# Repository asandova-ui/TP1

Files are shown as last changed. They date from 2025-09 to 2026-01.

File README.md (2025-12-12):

***ESTRUCTURA DE DESCOMPOSICIÓN DEL PROYECTO***
**Especificación del proyecto**
Definición de objetivos  
Estudio sistema  

**Diseño electrónico y captura esquemática PCB0** 
Búsqueda de componentes  
Posicionado componentes  
Creación de nuevos componentes  
Documentación esquemático. Control de cambios  
Análisis consumo eléctrico  
Análisis disipación de potencia  
Rutado de conexiones  
Generación de listado de materiales (BOM) 

**Diseño electrónico y captura esquemática PCB1** 
Búsqueda de componentes  
Posicionado componentes  
Creación de nuevos componentes  
Documentación esquemático. Control de cambios  
Análisis consumo eléctrico  
Análisis disipación de potencia  
Rutado de conexiones  
Generación de listado de materiales (BOM)  

**Diseño electrónico y captura esquemática PCB2** 
Búsqueda de componentes  
Posicionado componentes  
Creación de nuevos componentes  
Documentación esquemático. Control de cambios  
Análisis consumo eléctrico  
Análisis disipación de potencia  
Rutado de conexiones  
Generación de listado de materiales (BOM)  

**Diseño electrónico y captura esquemática PCB3** 
Búsqueda de componentes  
Posicionado componentes  
Creación de nuevos componentes  
Documentación esquemático. Control de cambios  
Análisis consumo eléctrico  
Análisis disipación de potencia  
Rutado de conexiones  
Generación de listado de materiales (BOM)  

**Diseño de la placa de circuito impreso PCB0** 
Creación de huellas de nuevos componentes  
Posicionado de componentes  
Definición de borde y zonas de conectores 
Rutado de conexiones  
Planos de disipación térmica  
Planos de masa y otros  
Documentación: serigrafía. Control de cambios 
Documentación: acotaciones geométricas  
Generación de ficheros para el fabricante (gerber)  

**Diseño de la placa de circuito impreso PCB1** 
Creación de huellas de nuevos componentes  
Posicionado de componentes  
Definición de borde y zonas de conectores 
Rutado de conexiones  
Planos de disipación térmica  
Planos de masa y otros  
Documentación: serigrafía. Control de cambios 
Documentación: acotaciones geométricas  
Generación de ficheros para el fabricante (gerber)  

**Diseño de la placa de circuito impreso PCB2** 
Creación de huellas de nuevos componentes  
Posicionado de componentes  
Definición de borde y zonas de conectores 
Rutado de conexiones  
Planos de disipación térmica  
Planos de masa y otros  
Documentación: serigrafía. Control de cambios 
Documentación: acotaciones geométricas  
Generación de ficheros para el fabricante (gerber)  

**Diseño de la placa de circuito impreso PCB3** 
Creación de huellas de nuevos componentes  
Posicionado de componentes  
Definición de borde y zonas de conectores 
Rutado de conexiones  
Planos de disipación térmica  
Planos de masa y otros  
Documentación: serigrafía. Control de cambios 
Documentación: acotaciones geométricas  
Generación de ficheros para el fabricante (gerber)  

**Fabricación de la placa de circuito impreso** 
Envío al fabricante  
Recepción y revisión  
Montaje de componentes  

**Realización Hardware FPGA**
Core: LarVA 
Periféricos: UART0/1/2, SPI0/1, Temporizador, GPOut, GPIn 
Simulación 

**Realización Firmware. Simulación y depuración** 
Control de elementos hardware: drivers  
Verificación  
Programa principal. Especificaciones  
Documentación firmware. Control de cambios  

**Verificación hardware** 
Verificación inicial  
Verificación firmware 
Resolución de problemas  
Análisis de prestaciones  
Montaje final. Piezas mecánicas  
Pruebas de campo 

**Documentación** 
Realización informe

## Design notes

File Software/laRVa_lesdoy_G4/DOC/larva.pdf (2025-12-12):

## LaRVa

## Last “Another RISC-v” from VAlladolid

J. Arias

## 1 Introduction

LaRVa is a minimal RV32E/RV32I core designed with three goals in mind:

1. It has to be simple, easy to understand, and to fit into small FPGAs.
2. It has to run fast.
3. It has to support vectored interrupts.

Goal #1 was dictated by the FPGAs we are using in lots of designs: the ICE40HX family from Lattice, and also by common sense.
Goal #2 implies a pipelined execution, something I explored with success in the design of the GUS16 processor, and that most simple RV cores, like “PicoRV” from Claire Wolf, or “FemtoRV” from Bruno Levy & Matthias Koch, lack. laRVa is going to execute one instruction each clock cycle, unless these instructions are loads, stores, or jumps.
Goal #3 demands some way to save the value of the PC when an interrupt is serviced. I resorted to use two different PC registers, one for normal mode and other for interrupts, so there is no need to save anything.
Why to design another CPU core? Well, the GUS16 was a successful design, but with a very big problem: It has no GCC toolchain! Its only tool is a lousy 2-pass assembler and that’s all folks. Apart from that it is a 16-bit design with many limitations. On the contrary, the RISC-V have a powerful toolchain maintained by GNU and it is a 32-bit design.
Of course, this design is going to present some challenges apart from the fact that it uses double the number of bits than the GUS16, like:
- A big register bank that can’t be mapped to internal RAM blocks (BRAMS). The problem with BRAMS is their synchronous read, or the fact that the data you are reading isn’t available until next clock edge, a time I don’t want to waste. 32 registers of 32 bits each will require no less than 1024 flip-flops or logic cells, so a 16-register approach (RV32E) could be a good idea to start with.
- A lot of sign extensions are needed for literals and also for the bytes and half-words read from memory. And, in some cases zero extensions.
- The usual ALU has to be complemented with a barrel shifter in order to support single cycle multi-bit shifts.
- The “Set Less Than” instructions also have to be supported in the ALU.
- Conditional branches do use the ALU for the checking of conditions (there are no comparisons, nor condition flags here), but they also require the addition of an literal offset to PC, thus, a second adder has to be included for the PC update during jumps.

- Talking about PC offsets. In the RISC-V ISA all offsets are related to the address of the current instruction, but in a pipelined processor the PC is going to point ahead of the instruction being executed. This fact has to be taken into account in the processor design (not in the assembler like in the GUS16 case, or ARMs, or many others)
- While the RISC-V ISA is very clear and concise about its base integer instructions, when it comes to privileged mode it becomes just the contrary. I’m not going to waste a single logic cell for the implementation of a “Vendor ID” register, profiling register, or any crap like that. I just want a minimally decent implementation of hardware interrupts, so, the only register I’m planning to implement is the “MEPC” (Machine Exception PC) along with the “MRET” instruction for copying it back to PC or something equivalent like the use of two PC registers.

## 2 LaRVa design

This processor follows a pipelined execution where two instructions are processed in parallel: One gets its op-code read from memory and the other gets executed. An Instruction register holds the op-code while a new one is being read, and all instructions must complete their execution in a single cycle. This last requirement leaves out the multiplication and division instructions and forces the use of a barrel shifter in the ALU, along with ruling out the use of BRAM blocks with synchronous outputs for the synthesis or the register file.
Also, not all instructions can be executed in this way: Load and Store operations have to address the memory during their execution cycle, and therefore, no op-code fetch can be carried out simultaneously. In this case an invalid op-code is stored in the instruction register and it has to be signaled and discarded. This results in the use of two effective clock cycles for the execution of Load or Store instructions. Something similar happens during jumps, where the op-code read into the instruction register is the one at the memory position following the jump instruction, and that instruction shouldn’t be executed. In the case of jumps two effective cycles are also employed, and conditional jumps will take two cycles if their condition is meet or just one cycle otherwise. Apart from these details, the design of the LaRVa core is quite conventional with three data buses: two inputs and one output to the ALU. A good deal of Verilog code was taken from the “FemtoRV” sources, specially that related to the ALU design or the Load/Store management. Some of this code remains almost untouched, like the mentioned Load/Store logic, while other was heavily modified, like the ALU. And, of course, some other code is completely new, like the register file, the the program counter stack (LaRVa has two PCs), and the interrupt logic, that was almost literally copied from the GUS16 design.
With respect to the FemtoRV design I want to remark the following changes:
- The ALU is now used for the computation of memory addresses during the execution of Load and Store instructions. The address bus is switched from the PC to the output of the ALU adder during these instructions.
- The ALU is also used for the computation of the jumping address for the JALR instruction, and the results of the AUIPC and LUI instructions.
- There are no separate adder and subtractor circuits in the ALU. These two blocks were merged.

### 2.1 General diagram

A general view of the design is presented in the following diagram:

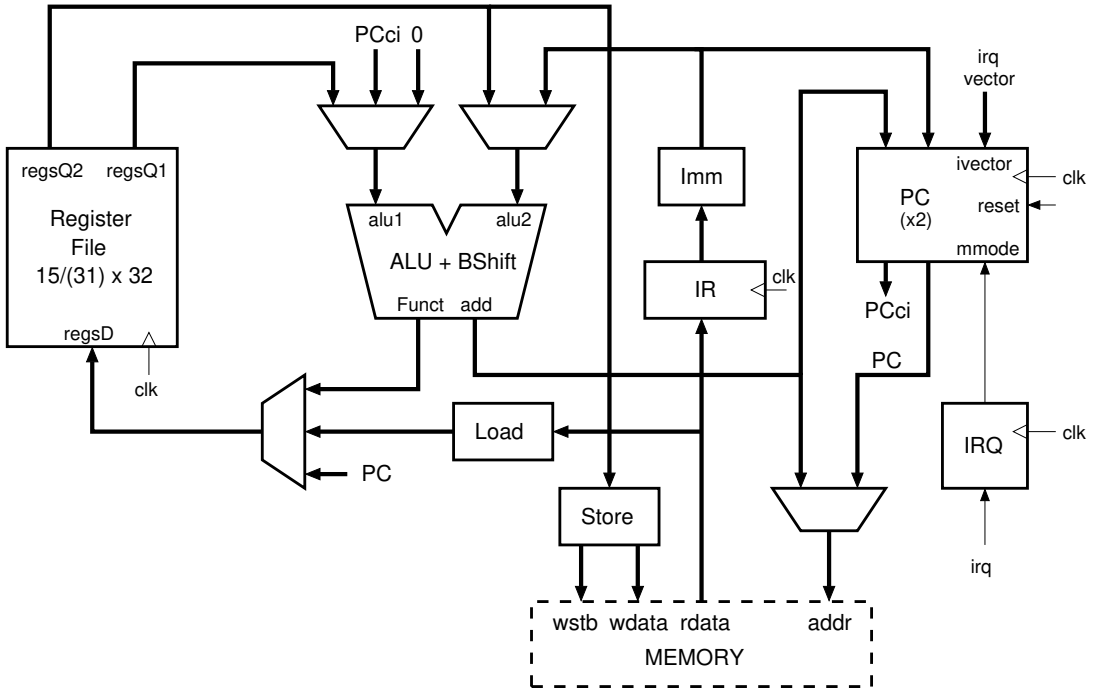
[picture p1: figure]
Register File 15/(31) x 32; regsD; regsQ2; regsQ1; add; Imm; Load; mmode; reset; IRQ; irq; clk; wstb wdata rdata; addr; MEMORY; Store; ALU + BShift; irq vector; ivector; alu1; alu2; Funct; PCci 0; PCci

Here, most blocks are combinational and they are controlled by the bits stored in the IR register, that holds the op-code of the instruction being executed. IR also holds the bits of the immediate values that are further processed in the Imm block, mainly for bit descrambling and sign extension.
The ALU includes mainly an adder and a barrel shifter. In its output the desired operation (ADD, SUB, AND, OR, XOR, Shifts,...) can be selected, but the output of the adder is also always present. This second output is used for the generation of the memory address during Load and Store instructions, and also by the JALR instruction (in fact, the main output of the ALU could also be used, but it has a little longer delay). The first ALU input is usually the contents of the register “rs1”, but it can be also the delayed PC for the AUIPC instruction or even zero for the LUI instruction. The second ALU input is selected between the register “rs2” or an immediate constant
The value written back to the register file (register “rd”) is the output of the ALU for most cases, a value derived from the data coming from memory for Load instructions, or the current value of the program counter (address of next instruction) for the JAL and JALR instructions. No value is written back in the case of Store, Branch, System instructions other than CSRRW, or in the case of invalid values in IR (pipeline stalls).
The program counter block will be described in detail next. Here I want to remark that it is actually a two-level stack that resembles the case of 8-bit PIC microcontrollers. One of its registers is used during normal program execution, while the other is switched in when an interrupt happens. The normal PC remains unchanged during the execution of interrupt routines and it is switched back when a return from interrupt (MRET) is executed. Also, while in normal mode, the interrupt PC gets preloaded with a vector that could be made different for each possible interrupt source.
The only remaining block is the one related to interrupt management, that will be detailed later.

### 2.2 Program counter

A more detailed diagram of the Program Counter logic is shown next:

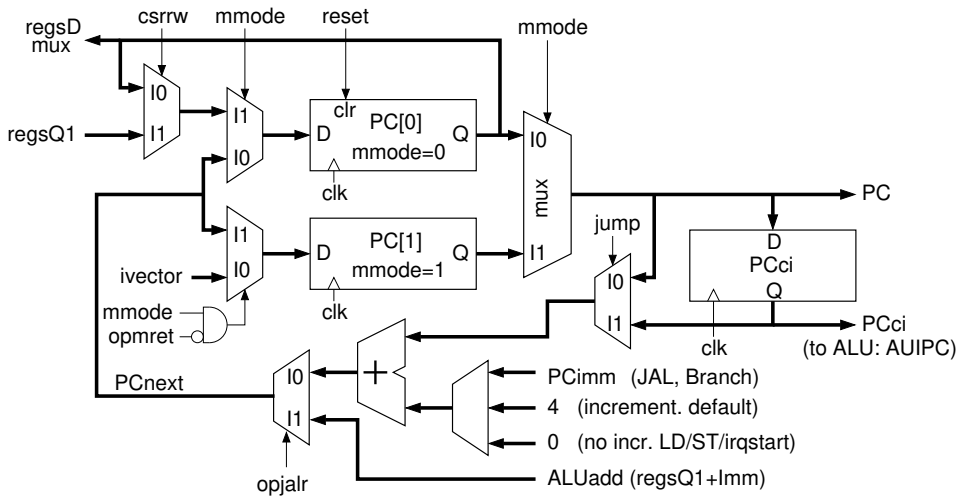
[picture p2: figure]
I1mux; mmode=0; PC[1] mmode=1; mmode; opmret; opjalr; (no incr. LD/ST/irqstart); (increment. default); PCnext; ivector; csrrw; reset; regsQ1; mux; regsD; ALUadd (regsQ1+Imm); PCimm (JAL, Branch); clr; clk; PCci; PCci Q; (to ALU: AUIPC); jump

The “mmode” signal selects which register to present at the output, and also the values written back to each register. In normal mode (mmode=0) the register PC[0] is selected as output and it is updated every clock cycle, while the register PC[1] is written with the value “ivector”, that is the address of the next interrupt service routine. In interrupt (AKA machine) mode PC[0] remains with it last value stored and PC[1] is presented at the output and updated.
There is also another register, “PCci” (PC of current instruction), where the PC value is copied, so, it has the same value as the PC but with a one cycle delay. This register holds the address of the instruction currently being executed and its contents are used for the computation of branch and JAL address, and for the AUIPC instruction. (I think a register is cheaper and faster than an adder for the subtraction of 4).
The update logic is built around an adder that allows the PC incrementing (as op-codes are 32-bit long the PC increments in steps of 4), the addition of offsets for the execution of conditional branches and the JAL instruction, or to leave the PC as it is (increment of 0), that is also required during the execution of Load and Store instructions, or when the mode changes to interrupt. The JALR instruction is an special case because the jumping address is computed in the ALU (the base register is one of the register file, not the PC), and the ALU output has to be switched in during the execution of JALR.
The actual update logic built in the Verilog source is functionally equivalent to that shown in the figure but a little different:

// Next PC logic

wire [31:0]PCadd1= PC+(irqstart | opload | opstore ? 0 : 4);

wire [31:0]PCadd2= PCci+PCimm;

wire [31:0]PCnext= opjalr ? aluAdder : (jump? PCadd2 : PCadd1);

Here two separate adders are used and their results switched depending on “jump”. “jump” is a decoded signal for a taken jump and it can have a quite long delay due to the checking of condition codes in the ALU. This delay would be added to that of the PC update adder if the logic of the figure is implemented as shown. The actual implementation is faster because all adders are going to have a valid result more or less as the same time when “jump” becomes valid, but it requires more logic.
The AND gate that controls the writing of PC[1] is intended for the chaining of interrupts, and it forces the writing of “ivector”, even in interrupt mode, when the MRET instruction is executed.
I want to notice that during interrupt mode the register PC[0] is acting as an effective MEPC (Machine Exception PC) and it would be interesting to be able to read and to modify it. That would provide support for task switching. In order to have a minimally compliant implementation of the related privileged ISA the CSRRW instruction was also added to the core instruction set, yet restricted to its use with the control/status register #0x341 (MEPC). This instruction allows the atomic read plus write of the MEPC register, that is in fact PC[0].
So, now we have two privileged instructions that can be used only in machine mode. If they are executed in the normal user mode they will fail for sure. These instructions are:
1. MRET. When executed in machine mode returns to user mode and restores the original PC (if there are no interrupts still pending) returning to the interrupted program. If executed in user mode it does nothing.
2. CSRRW rd,0x341,rs1. When executed in machine mode copies the value of PC[0] (MEPC) to “rd” and the value of “rs1” to PC[0]. No other offsets in the CSR space are allowed. If executed in user mode PC[0] isn’t written, but in “rd” we get the current value of PC.

On the other hand, the instructions ECALL and EBREAK (software interrupts) will do nothing if executed in machine mode.

### 2.3 Interrupts

The servicing of an interrupt implies the changing of the “mmode” signal to 1, but this has to be done in a proper sequence in order to avoid disturbing the instruction being executed. That instruction has to complete its execution cycle with the normal PC still selected. In order to achieve this an “irqstart” signal is set during just one clock cycle before “mmode” is set , and this signal will cause a pipeline stall, so no instruction will be executed with a wrong PC register selected.
The details of such sequencing are shown in the next chronograph:

mmode

irqstart

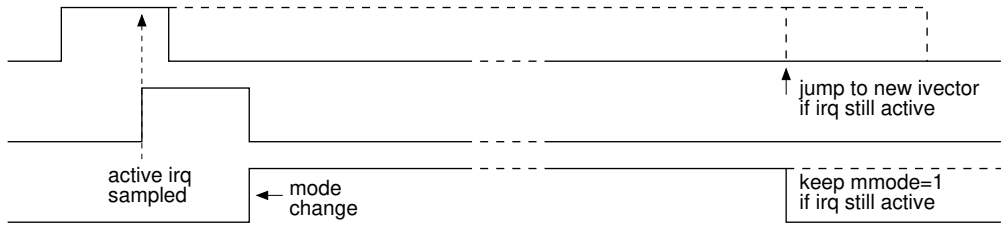
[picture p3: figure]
jump to new ivector; change; mode; keep mmode=1; sampled; active irq; if irq still active

irq

clk

opvalid | invalid fetch
discard | discard

MRET

Exec

Fetch
MRET
op−code | op−code

invalid
fetch
no PC
incr.

Also, at the end of the interrupt routine an MRET instruction is executed. That instruction usually returns “mmode” to 0 and causes a pipeline stall just like any other jump, but, if the “irq” line is still active “mmode” remains at 1 and interrupts are thus chained.
The circuit diagram for the interrupt sequencing is shown next. It is almost the same as in the GUS16 core:

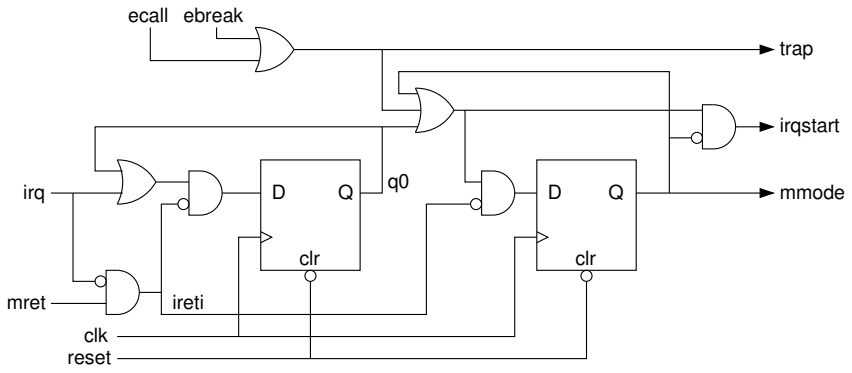
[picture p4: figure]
clr; reset; irq; clk; mret; trap; mmode; ecall ebreak; ireti; irqstart

There was also a need for some sort of “software interrupt”, so, the ECALL and EBREAK opcodes were also decoded and they act in a similar way to the “irqstart” signal, entering the interrupt mode. But I didn’t want to provide a particular interrupt vector for these opcodes, so, I resorted to provide a “trap” output for the core that can be routed to an external vectored interrupt controller just like any other interrupt from a peripheral.

### 2.4 Memory interface & Wait States

The LaRVa core has a simple memory interface, including:

- “[31:2]addr”, the memory address. It lacks the two lower bits because these address are for bytes and the data bus is 32-bit wide.
- “[31:0]rdata”, the data read from the memory/IO system. Its has 32 bits, but for byte and half-word loads some of these bits are ignored.
- “[31:0]wdata”, the data to write to the memory/IO system. For byte and half-word stores some of these bits are invalid and shouldn’t be written (see write strobes next).
- “[3:0]wstrb”, the four write strobes:
wstrb | bits to write | Instruction
0001 | wdata[7:0] | SB
0010 | wdata[15:8]
0100 | wdata[23:16]
1000 | wdata[31:24]
0011 | wdata[15:0] | SH
1100 | wdata[31:16]
1111 | wdata[31:0] | SW

I want to remark that “addr” changes after each rising edge of “clk” and “rdata” must be valid before the next rising edge. Or in other words: The memory is supposed to be an asynchronous one. If this core is to be interfaced to a synchronous RAM, like that found inside FPGAs, it’s a good idea to use an inverted clock for the memory. That would change the RAM output on the falling edges, half a cycle before its sampling by the core.
With respect to other cores, like PicoRV or FemtoRV, there are two control lines missing:
- “mem_valid” output. The LaRVa core is reading or writing the memory all the clock cycles, so, a “mem_valid” signal would be always active.
- “mem_ready” input. There is no control input to force the insertion of wait states in the core. This may difficult the interfacing of slow memory devices, like the “SPI_flash_as_ROM” ones, or other memorymaster devices like video controllers or DMA. But not too much. The trick here is to force the core clock as high when wait cycles have to be inserted and it requires a simple OR gate (a trick taught by Mr Clive Sinclair in its ZX Spectrum).

### 2.5 Interrupt interface

The core has two inputs and one output related to interrupts. These are:

- “irq”. This input requests a change to interrupt (machine) mode and a jump to an interrupt service routine when high. The ISR starts its execution two clock cycles after “irq” is sampled high.

- “[31:2]ivector”. A 30-bit interrupt vector with the address of the interrupt routine to jump. Code addresses have to be multiple of 4, so, the bits 1 and 0 are missing.
- “trap”. An output that signals the execution of a software interrupt (or environment call, system call, kernel entry, or whatever you like to call it). The only instructions that make “trap” to go high are ECALL and EBREAK. This signal can be used to generate a convenient vector address for these software interrupts outside the core. In the external interrupt controller “trap” has to have the maximum priority or ECALL/EBREAK interrupts could be missed if a higher priority interrupt happens at the same time (“trap” is active for only one cycle). In the LaRVa core there is no difference between ECALL and EBREAK, but a trap handler could read the value of MEPC, inspect the opcode of the interrupting instruction, and take a different course of action depending on it.

## 3 Performance

The LaRVa core is supposed to be fast and this ought to be tested. As a benchmark I wrote an small program in C language that does fixed-point FFTs and ran it in both the LaRVa and PicoRV cores. I would like to include the FemtoRV core too, but the naked truth is that I never got working the same core I used for much of the LaRVa logic, and I don’t want to expend more time on it.
Both cores were running at 18MHz, but while LaRVa was just an RV32E core without support for multiplications, the PicoRV core was an RV32IMC that included multiplications in its instruction set. And multiplications are the very basic processing block for FFTs. But anyway, the times taken for the calculation of 400 FFTs with 128, 16-bit, samples each were recorded.
Along with the FFT I also included another different test: An Eratosthenes sieve for finding the prime numbers below 2048. This last test is less dependent on multiplications and more on multi-bit shifts. The results for both test are:
Core | ISA | Fixed-point FFT | Eratosthenes sieve
measured Time | speed factor | measured Time | speed factor
PicoRV | RV32E | 18.31 s | 95% | 36.71 ms | 94%
| RV32I | 17.36 s | 100% | 34.52 ms | 100%
| RV32IC | 17.53 s | 99% | 35.65 ms | 97%
| RV32IM | 3.69 s | 470% | 20.45 ms | 169%
LaRVa | RV32E | 6.63 s | 262% | 13.60 ms | 254%

Here we can see that the ISA chosen for the PicoRV has little impact on the time unless there are multiplications involved. Leaving multiplications apart we see that the LaRVa core runs 2.76 times faster when executing exactly the same code than the PicoRV. This is almost what was expected because LaRVa is 3 times faster for normal instructions and 2.5 times faster for loads, stores, and jumps, according to the times stated by Claire. If we take the advantage of a larger register file into account the picture doesn’t change too much, the time is reduced by only a 5%. Also, the use of a compressed instruction set leaves the execution time almost unchanged. Only when we add hardware multiplications to the ISA we can see an spectacular improvement in execution time for the FFT test, but we must recall this test is heavily biased towards multiplication efficiency. For the Eratosthenes sieve the execution time is also reduced in the RV32IM case, but not as much. In this case the improvement is due to the DIV and REM instructions used during binary to decimal conversion for the printing of the prime numbers (The I/O time of the output peripheral isn’t included in the table).
An still faster multiplication for the PicoRV was untested because I ran out of FPGA space when synthesizing it.

To be honest, the LaRVa was running at its maximum clock frequency while the PicoRV still could be made to run a 34% faster because its maximum clock frequency was 24.26MHz. But still, if we take into account the maximum clock frequencies reported by “nextpnr” and we scale the times accordingly, the LaRVa core runs almost twice as fast than the PicoRV core as long as the code don’t rely heavily on multiplications.

## 4 Multitasking

Or multitrheading, or... Names change with time but things are still the same. In order to switch to a different task we have to:

- Switch to privileged mode. This can be done via executing ECALL or by a peripheral interrupt.
- Save all the register values in a memory area. The stack of the task would be a convenient place (each task is going to have its private stack area)
- Save also the value of the MEPC register.
- Save the current value of the stack pointer in a task table.
- Now, select a different task to switch and get the value of its stack pointer.
- Read the MEPC value from the new stack and write it to MEPC.
- Read the values of all the registers from the stack.
- Go back to user mode by executing MRET.

An example of a simple Round-Robin task switcher is listed next:

void __attribute__((naked)) task_switch() {
asm volatile(
" | addi | sp,sp,-60 | \n"
" | sw | x1,0(sp) | \n"
" | sw | x3,4(sp) | \n"
" | sw | x4,8(sp) | \n"
" | sw | x5,12(sp) | \n"
" | sw | x6,16(sp) | \n"
" | sw | x7,20(sp) | \n"
" | sw | x8,24(sp) | \n"
" | sw | x9,28(sp) | \n"
" | sw | x10,32(sp) | \n"
" | sw | x11,36(sp) | \n"
" | sw | x12,40(sp) | \n"
" | sw | x13,44(sp) | \n"
" | sw | x14,48(sp) | \n"
" | sw | x15,52(sp) | \n"
" | csrrw | x1,0x341,zero | \n" // Interrupted PC
" | sw | x1,56(sp) | \n"
" | mv | a0,sp | \n"
" | call | getnextsp | \n"
" | mv | sp,a0 | \n"
" | lw | x1,56(sp) | \n"
" | csrrw | zero,0x341,x1 | \n" // Interrupted PC
" | lw | x1,0(sp) | \n"
" | lw | x3,4(sp) | \n"
" | lw | x4,8(sp) | \n"
" | lw | x5,12(sp) | \n"
" | lw | x6,16(sp) | \n"
" | lw | x7,20(sp) | \n"
" | lw | x8,24(sp) | \n"
" | lw | x9,28(sp) | \n"
" | lw | x10,32(sp) | \n"
" | lw | x11,36(sp) | \n"
" | lw | x12,40(sp) | \n"
" | lw | x13,44(sp) | \n"
" | lw | x14,48(sp) | \n"
" | lw | x15,52(sp) | \n"
" | addi | sp,sp,60 | \n"
" | mret | | \n"
);
}

// task table
#define MAXTSK 4

struct {
uint32_t tskix; | // Current task index
uint32_t tsksp[MAXTSK]; // list of SPs
} tsktab;

// Scheduler: round-robin: Saves SP and gets a new one fron the task list uint32_t getnextsp(uint32_t sp)
{
uint32_t i;
i=tsktab.tskix;
tsktab.tsksp[i]=sp;
i++;
if (!tsktab.tsksp[i]) i=0; // Task list ends with SP=0 sp=tsktab.tsksp[i];
tsktab.tskix=i;
return sp;
}

#define STKSZ0 (1<<10) // Stack size for task 0

void init_task()
{
uint32_t *sp;
sp=(uint32_t *)(0x20000000+(128<<10)-STKSZ0);
sp=&sp[-15];
sp[14]=(uint32_t) tetris_task1; // PC of task #1 at its stack
tsktab.tskix=0; | // Current task number
// task #0 is the current code and needs no initialization
tsktab.tsksp[1]=(uint32_t)sp; | // SP of task #1
tsktab.tsksp[2]=0; | // End of task list
IRQVECT0=(uint32_t)task_switch; // trap vector
}

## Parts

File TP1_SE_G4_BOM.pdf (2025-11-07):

## Bill Of Materials for Taller Proyectos 1. Datalogger

Design Title | Taller Proyectos 1. Datalogger
Author | G4: Andrés, Iván, Lucía, Víctor R, Alonso
Document Number | 1
Revision | 1
Board | PCB0-Power-USB
Design Created | miércoles, 21 de septiembre de 2022
Design Last Modified viernes, 7 de noviembre de 2025

### Total Parts In Design 61

### Notes

Falta el IVA (21%)
9 Capacitors
Quantity References | Value | Stock Code | PCB Package | Unit
| | | | | Cost
2 | C20,C26 | 100nF | . | 0805 | €0,10
4 | C21-C24 | 22uF | . | 0805 | €0,09
1 | C25 | 1uF | . | 0805 | €0,12
2 | C27-C28 | 33pF | . | 0805 | €0,10
Sub-totals: | | | | | €0,88
16 Resistors
Quantity References | Value | Stock Code | PCB Package | Unit
| | | | | Cost
1 | R15 | 220R | . | 0805 | €0,09
3 | R16,R27-R28 | 2k2 | . | 0805 | €0,09
1 | R17 | 71.5k | . | 0805 | €0,09
4 | R18,R23-R24,R30 | 10k | . | 0805 | €0,09
2 | R19-R20 | 0R1 | . | 0805 | €0,09
2 | R21-R22 | 470R | . | 0805 | €0,09
2 | R25-R26 | 680R | . | 0805 | €0,09
1 | R29 | 4k7 | . | 0805 | €0,09
Sub-totals: | | | | | €1,44
4 Integrated Circuits
Quantity References | Value | Stock Code | PCB Package | Unit
| | | | | Cost
1 | U4 | MCP73831/2 | Farnell 1332157 | SOT23-5 | €0,64
1 | U5 | MCP1725ADJ | Farnell 1834878 | SO8 | €0,66
1 | U6 | CY7C65213-28PVXI Farnell 2772892 | SOP65P780X200-28 €1,73
1 | U7 | LPC1112FD20/102 | Mouser 771- LPC1112FD20/1025 | SO20W | €2,47
Sub-totals: | | | | | €5,50
3 Diodes
Quantity References | Value | Stock Code | PCB Package | Unit
| | | | | Cost
2 | D2-D3 | KA-3022SRC-4.5SF- TR | Farnell 4665975 | SOD123_K | €0,45
1 | D4 | KA-3022SGC-4.5SF Farnell 1142615 | SOD123_K | €1,68
Sub-totals: | | | | | €2,58
29 Miscellaneous
Quantity References | Value | Stock Code | PCB Package | Unit
| | | | | Cost

21 | /BOOT,/HOLD,/ICE_RESET,/RESET,
/SS,/WP,3V3,3V7,3V3M,3V7M,5V, GND,ICE_CLK,ICE_DONE,MISO, MOSI,RXD,SCK,TXD,USB_D+,USB_D-
PIN | PIN | €1,86
1 | BAT | 530480310 | Digikey WM1743- ND | 530480310 | €2,60
1 | BAT1 | LIPO BAT | ampul AM9299 | NULL | €3,20
1 | J4 | USB Mini B Molex 67503-1230 | Farnell 2847248 | MOLEXUSB MINI B 67503-1230 | €11,40
1 | J11 | 2214S-40SG-85 | Farnell 2847248 | CONN-DIL40- ROUND | €0,65
1 | J12 | 2214S-40GS-85 | Farnell 2313554 | CONN-DIL40- ROUND | €0,65
1 | L1 | MMZ1608B121C | Farnell 2800823 | RESC1608X84 | €0,09
1 | SW1 | OS102011MA1QS1 | Farnell 2435103 | OS102011MA1QS1 €4,55
1 | X1 | QT49-12.000MEEJ- B | Farnell 4200031 | QT49-12.000MEEJ- B | €0,35
Sub-totals: | | | | | €62,55
Totals: | | | | | €72,95

viernes, 7 de noviembre de 2025 11:16:01

## Bill Of Materials for Taller Proyectos 1. Datalogger

Design Title | Taller Proyectos 1. Datalogger
Author | G4: Andrés, Iván, Lucía, Víctor R, Alonso
Document Number | 1
Revision | 1
Board | PCB1-FPGA
Design Created | miércoles, 21 de septiembre de 2022
Design Last Modified viernes, 7 de noviembre de 2025

### Total Parts In Design 94

### Notes

Falta el IVA (21%)
20 Capacitors
Quantity References | Value | Stock
| | | Code | PCB Package | Unit Cost
16 | C1-C8,C11-C17,C20 | 100nF | . | 0805 | €0,10
2 | C9-C10 | 10uF | . | 0805 | €0,10
2 | C18-C19 | 22uF | . | 0805 | €0,09
Sub-totals: | | | | | €1,98
51 Resistors
Quantity References | Value | Stock
| | | Code | PCB Package | Unit Cost
6 | R1,R9-R10,R14,R49-R50 | 10k | . | 0805 | €0,09
2 | R2,R47 | 33k | . | 0805 | €0,09
2 | R3-R4 | 100R | . | 0805 | €0,09
3 | R5-R7 | 2k2 | . | 0805 | €0,09
1 | R8 | 0R1 | . | 0805 | €0,09
1 | R11 | 12k | . | 0805 | €0,09
1 | R12 | 4k7 | . | 0805 | €0,09
1 | R13 | 1k5 | . | 0805 | €0,09
4 | R15-R18 | 680R | . | 0805 | €0,09
9 | R19,R21,R23,R28,R30,R32,R37,R39, R41 | 180R | . | 0805 | €0,09
15 | R20,R22,R24-R25,R27,R29,R31,R33- R34,R36,R38,R40,R42-R43,R18B | 330R | . | 0805 | €0,09
3 | R26,R35,R44 | 130R | . | 0805 | €0,09
2 | R45-R46 | 68R | . | 0805 | €0,09
1 | R48 | 0R | . | 0805 | €0,09
Sub-totals: | | | | | €4,59
4 Integrated Circuits
Quantity References | Value | Stock
| | | Code | PCB Package | Unit Cost
1 | U1 | ICE40HX4K-TQ144 | Farnell
| | | 3768754

QFP50P2200X2200X160-144N €9,20

1 | U2 | IS25LP032D-JNLE | Farnell
| | | 1852016 | SO8W | €2,63
1 | U3 | MCP1725ADJ | Farnell | SO8 | €1,05
1 | U5 | MCSJK-3N-16-3.3-50- B | Farnell | MCSJK3N16003350B
Sub-totals: | | | | | €12,88

5 Diodes
Quantity References | Value | Stock
Code
| | | PCB Package | Unit Cost
1 | D1 | 1N4448HWS | Farnell
3127174
| | | SOD-323 | €0,12
2 | D2-D3 | KA-3022SRC-4.5SF- TR
Fernell
4665975
| | | SOD-323 | €0,34
1 | D4 | KA-3022SRC-4.5SF- TR
Fernell
4665975
| | | SOD-323 | €0,45
1 | D5 | KA-3022SRC-4.5SF- TR
Fernell
4665975
| | | SOD-323 | €0,38
Sub-totals: | | | | €1,63
14 Miscellaneous
Quantity References | Value | Stock
Code
| | | PCB Package | Unit Cost
7 | 1V2,1V2M,BLUE,GREEN,HSY,RED, VSYNC | PIN | PIN
2 | 3V3,GND | PIN | PIN | €0,00
2 | J1-J2 | M20-6102045 | Farnell
1569230
| | | CONN-DIL40-ROUND | €5,32
1 | J3 | L77HDE15SD1CH4F Farnell
2401182
| | | L77HDE15SD1CH4F | €1,88
2 | MB0-MB1 | SPC20485 | Farnell
1258956
| | | CONN-SIL2 | €0,46
Sub-totals: | | | | €13,44
Totals: | | | | €34,52

viernes, 7 de noviembre de 2025 11:16:21

## Bill Of Materials for Taller Proyectos 1. Datalogger

Design Title | Taller Proyectos 1. Datalogger
Author | | G4: Andrés, Iván, Lucía, Víctor R, Alonso
Document Number | 1
Revision | 1
Board | PCB2-Sensors
Design Created | miércoles, 21 de septiembre de 2022
Design Last Modified viernes, 7 de noviembre de 2025

### Total Parts In Design 53

### Notes

Falta el IVA (21%)
5 Modules
Quantity References | Value | Stock
| | | Code | PCB Package | Unit Cost
1 | M1 | BME680_MODULE Mouser
| | | BME680

BME680_MODULE €18,39

1 | M2 | GP2Y1010AU0F | Farnell
| | | 9707956 | GP2Y1010AU0F | €8,64
1 | M3 | GPS_TEL09132 | Farnell
| | | 3769990 | GPS_TEL0132 | €17,17
1 | M4 | SEN0134 | Farnell
| | | 2946118 | SEN0134 | €7,80
1 | M2_ON | PIN | | PIN
Sub-totals: | | | | | €52,00
6 Capacitors
Quantity References | Value | Stock
| | | Code | PCB Package | Unit Cost
3 | C1-C3 | 1uF | . | 0805 | €0,12
2 | C4-C5 | 10uF | . | 0805 | €0,10
1 | C6 | EEEFK1V221P | Farnell
| | | 9695877 | EEHZT1E331UP | €0,60
Sub-totals: | | | | | €1,16
11 Resistors
Quantity References | Value | Stock
| | | Code | PCB Package | Unit Cost
6 | R1-R2,R5-R7,R11 | 10k | . | 0805 | €0,09
1 | R3 | 6k8 | . | 0805 | €0,09
1 | R4 | 1k2 | . | 0805 | €0,09
1 | R8 | 820R | . | 0805 | €0,09
1 | R9 | 470R | . | 0805 | €0,09
1 | R10 | 150R | . | 0805 | €0,09
Sub-totals: | | | | | €0,99
3 Integrated Circuits
Quantity References | Value | Stock
| | | Code | PCB Package | Unit Cost
1 | U1 | MS8607-02BA01 | Farnell
| | | 2748850 | QFN_5X3_NEG | €9,20
1 | U2 | MCP3004 | Farnell | DIL14 | €2,63

1 | U3 | XC9141B50DMR-G Farnell
SOT23-5 | €1,05
Sub-totals: | €12,88
4 Transistors
Quantity References | Value | Stock
Code
PCB Package | Unit
Cost
3 | Q1,Q3-Q4 | MMBT3904-7-F | Farnell
| | | 1773602

SOT95P230X109-3 €0,10

1 | Q2 | NDS332P | Farnell
| | | 1471069
SOT23 | €0,52
Sub-totals: | €0,82
24 Miscellaneous
Quantity References | Value | Stock
| | | Code
PCB Package | Unit
Cost
21 | 3V3,5V_CE,5V_M4,5V_UP,ADCCS,BMECS,CH0- CH3,EN1V4,EN5V,GND,GPS_RX,GPS_TX, ICEMISO,ICEMOSI,ICESCK,P25,SCL,SDA
PIN | PIN
2 | J1-J2 | M20-6102045 | Farnell
| | | 1569230

CONN-DIL40-
ROUND

€5,32

1 | L1 | LQH5BPN4R7NT0L Farnell
| | | 2219307

LQH5BPB100MT0L €0,32

Sub-totals: | €10,96
Totals: | €78,81
| | | viernes, 7 de noviembre de 2025 11:16:36

## Bill Of Materials for Taller Proyectos 1. Datalogger

Design Title | Taller Proyectos 1. Datalogger
Author | | G4: Andrés, Iván, Lucía, Víctor R, Alonso
Document Number | 1
Revision | 1
Board | PCB3-Wireless
Design Created | miércoles, 21 de septiembre de 2022
Design Last Modified viernes, 7 de noviembre de 2025

### Total Parts In Design 19

### Notes

Falta el IVA (21%)
1 Modules
Quantity References | Value | Stock Code | PCB Package | Unit
| | | | | Cost
1 | M3 | LAMBDA62-8D Farnell
| | | 2988568 | LAMBDA628D | €16,59
Sub-totals: | | | | | €16,59
3 Capacitors
Quantity References | Value | Stock Code | PCB Package | Unit
| | | | | Cost
1 | C1 | 100nF | . | 0805 | €0,10
2 | C2-C3 | 1nF | . | 0805
Sub-totals: | | | | | €0,10
1 Resistors
Quantity References | Value | Stock Code | PCB Package | Unit
| | | | | Cost
1 | R1 | 10k | . | RESC2012X50 | €0,09
Sub-totals: | | | | | €0,09
14 Miscellaneous
Quantity References | Value | Stock Code | PCB Package | Unit
| | | | | Cost
10 | 3V3,GND,LBUSY,LCS,LDI01,LMISO,LMOSI,LRX, LSCK,LTX | PIN | | PIN
1 | ANT1 | ANT | | ANTENA25-26
2 | J1-J2 | M20-6102045 | Farnell
| | | 1569230 | CONN-DIL40- ROUND | €5,32
1 | L1 | 1uH | . | 0805
Sub-totals: | | | | | €10,64
Totals: | | | | | €27,42

viernes, 7 de noviembre de 2025 11:16:43

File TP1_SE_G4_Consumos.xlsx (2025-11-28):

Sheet: Electrico
ANÁLISIS ELÉCTRICO
Grupo 4: Andrés, Iván, Lucía, Víctor R, Alonso
PCB0
ID | Componente | Voltaje (V) |  | Condiciones | I consumo (mA) | P disipada (W)
U4 | MCP73831/2 | 5 |  | Charging | 1.5 | 0.0075
U5 | MCP1725ADJ | 5 |  |  | 0.22 | 0.0011
R15 | R15 (220OHM) |  |  |  | 13.86363636 | 0
D2 | KA-3022SRC-4.5SF-TR | 5 | 1,95V Forward |  | 13.86363636 | 0.06931818182 | 5V ánodo - 1.95V Forward = voltaje en R15. Suponiendo que la corriente es máxima, al otro lado de R15 hay 0V. El diodo LED consume la misma corriente que la R15
 |  |  |  |  |  | 0
D3 | KA-3022SRC-4.5SF-TR | 3V3 | 1,95VForward |  | 2.020958084 | 0.006669161677 | Same working principle as D4
R25
D4 | KA-3022SGC-4.5SF | 3V3 | 1,85VForward |  | 2.170658683 | 0.007163173653 | 1.85V Forward para que en la resistencia XX caiga la mayor tensi´n posible y así hacer la corriente máxima
R26 | R26(668OHM) |  |  |  | 2.170658683 | 0
 |  |  |  |  |  | 0
U6 | CY7C65213-28PVXI | 5V |  |  | 18 | 0.09 | Maximum operating supply current
U7 | LPC1112FD20/102 | 3V3 |  | supply | 7 | 0.0231 | LPC1100L series (LPC111x/002/102/202/302) power consumption in low-current mode[
PCB1
ID | Componente | Voltaje (V) |  | Condiciones | I consumo (mA) | P disipada (W)
U2 | IS25LP032D-JNLE | 3V3 |  | Program Current | 25 | 0.0825
U3 | MCP1725ADJ | 3V3 |  |  | 0.22 | 0.000726
U5 | MCSJK-3N-16-3.3-50-B | 3V3 |  |  | 15 | 0.0495
D2 | KA-3022SGC-4.5SF | 3V3 | 1,85VForward |  | 2.132352941 | 0.003091911765 | (3,3-1,85)/680
D3 | KA-3022SGC-4.5SF | 3V3 | 1,85VForward |  | 2.132352941 | 0.003091911765
D4 | KA-3022SGC-4.5SF | 3V3 | 1,85VForward |  | 2.132352941 | 0.003091911765
D5 | KA-3022SGC-4.5SF | 3V3 | 1,85VForward |  | 2.132352941 | 0.003091911765
PCB2
ID | Componente | Voltaje (V) |  | Condiciones | I consumo (mA) | P disipada (W)
U1 | MS8607-02BA01 | 3V3 |  | Peak T/P conversion | 1.25 | 0.004125
M1 | BME680_MODULE | 3V3 |  | Pressure measure | 0.849 | 0.0028017
U2 | MCP3004 | 3V3 |  | Current drain | 0.15 | 0.000495
M3 | GPS_TEL09132 | 3V3 |  | Peak current | 100 | 0.33
M2 | GP2Y1010AU0F | 5V |  | Supply current | 20 | 0.1
U3 | XC9141B50DMR-G | 5V |  | quiescent | 0.04 | 0.0002
M4 | SEN0134 | 5V
PCB3
ID | Componente | Voltaje (V) |  | Condiciones | I consumo (mA) | P disipada (W)
M3 | LAMBDA62-8D | 3V3 |  | TX22dBm 868MHz | 118 | 0.3894

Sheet: Termico
ANÁLISIS TÉRMICO
Grupo 4: Andrés, Iván, Lucía, Víctor R, Alonso
PCB0
ID | Componente | Voltaje (V) | V salida | Potencia (mW) | Thermal Junction (ºC/W) | Temperatura (ºC) | I entrada (mA)
U4 | MCP73831/2 | 5 | 3V7 | 1.95 | 230 | 0.4485 | 1.5
U5 | MCP1725ADJ | 5 | 3V3 | 850.374 | 163 | 138.610962 | 500.22
R15 | R15 (220OHM) | 3.05 | 0 | 42.28409091 |  |  | 13.86363636
D2 | KA-3022SRC-4.5SF-TR | 5 |  |  |  |  | 13.86363636 | Sin calentamiento, toda la energía se transforma en luz
D3 | KA-3022SRC-4.5SF-TR | 3V3 |  |  |  |  | 2.020958084 | Sin calentamiento, toda la energía se transforma en luz
R25 |  | 1.35 | 0 | 2.728293413
D4 | KA-3022SGC-4.5SF | 3V3 |  |  |  |  | 2.170658683 | Sin calentamiento, toda la energía se transforma en luz
R26 | R26(668OHM) | 1.45 | 0 | 3.14745509 |  |  | 2.170658683
U6 | CY7C65213-28PVXI | 5V | 0 | 90 | - |  | 18
U7 | LPC1112FD20/102 | 3V3 | 0 | 23.1 | 116.3 | 2.68653 | 7
PCB1
ID | Componente | Voltaje (V) | V salida | Potencia (mW) | Thermal Junction (ºC/W) | Temperatura (ºC) | I consumo (mA)
U2 | IS25LP032D-JNLE | 3V3 | 0 | 82.5 | 8 | 0.66 | 25
U3 | MCP1725ADJ | 3V3 | 1V2 | 1050.462 | 163 | 171.225306 | 500.22
U5 | MCSJK-3N-16-3.3-50-B | 3V3 | 0 | 49.5 | - |  | 15
D2-5 | KA-3022SGC-4.5SF | 3V3 | 1,85VForward |  |  |  | 2.132352941 | Sin calentamiento, toda la energía se transforma en luz
R15-18 | 680OHM | 1.45 | 0 | 3.091911765
PCB2
ID | Componente | Voltaje (V) | V salida | Potencia (mW) | Thermal Junction (ºC/W) | Temperatura (ºC) | I consumo (mA)
U1 | MS8607-02BA01 | 3V3 | 0 | 4.125 | - |  | 1.25
M1 | BME680_MODULE | 3V3 | 0 |  | - |  | 0.849
U2 | MCP3004 | 3V3 | 0 | 0.495 | 108 |  | 0.15
M3 | GPS_TEL09132 | 3V3 | 0 | 330 | - |  | 100
M2 | GP2Y1010AU0F | 5VUP | 0 | 100 | - |  | 20
U3 | XC9141B50DMR-G | 5V | 0 | 0.2 | - |  | 0.04
M4 | SEN0134 | 5V | 0 |  | -
PCB3
ID | Componente | Voltaje (V) | V salida | Potencia (mW) |  |  | I consumo (mA)
M3 | LAMBDA62-8D | 3V3 | 0 | 389.4 | - |  | 118

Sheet: Ordenado
5V | Nombre | Consumo (mW)
U5 | MCP1725ADJ | 850.374
U4 | MCP73831/2 | 1.95
U6 | CY7C65213-28PVXI | 90
D2 +R15 | KA-3022SRC-4.5SF-TR | 42.28409091
M4 | SEN0134 | 0
U3 | XC9141B50DMR-G | 1050.462
 |  | 2035.070091
3V3 | Nombre | Consumo (mW)
U3 | MCP1725ADJ | 1050.462
D3 | KA-3022SRC-4.5SF-TR
D4 | KA-3022SGC-4.5SF
U7 | LPC1112FD20/102 | 23.1
U2 | IS25LP032D-JNLE | 82.5
U5 | MCSJK-3N-16-3.3-50-B | 49.5
D2-5 | KA-3022SGC-4.5SF
R15-18 | 680OHM
U1 | MS8607-02BA01 | 4.125
M1 | BME680_MODULE | 0
U2 | MCP3004 | 0.495
M3 | GPS_TEL09132 | 330
M3 | LAMBDA62-8D | 389.4
 |  | 1929.582
5VUP | Nombre | Consumo(mW)
M2 | GP2Y1010AU0F | 100

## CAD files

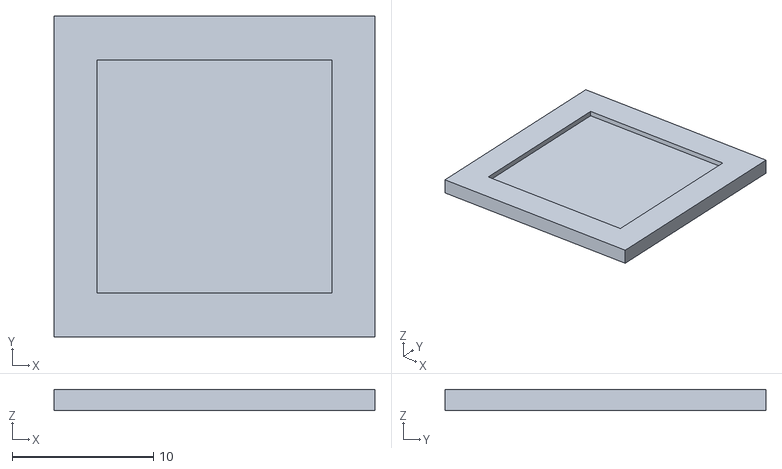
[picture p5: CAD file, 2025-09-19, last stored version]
Encapsulado/Box/files/Supply_Drop_Top.stl
22.8 x 22.8 x 1.50

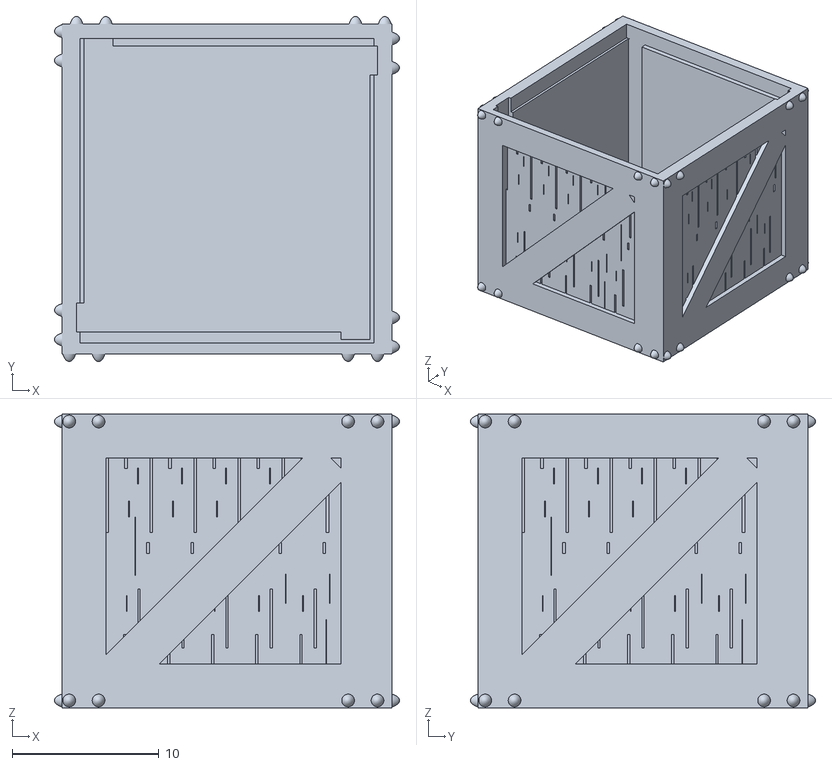
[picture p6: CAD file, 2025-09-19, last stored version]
Encapsulado/Box/files/Supply_Drop.stl
23.5 x 23.5 x 20.0

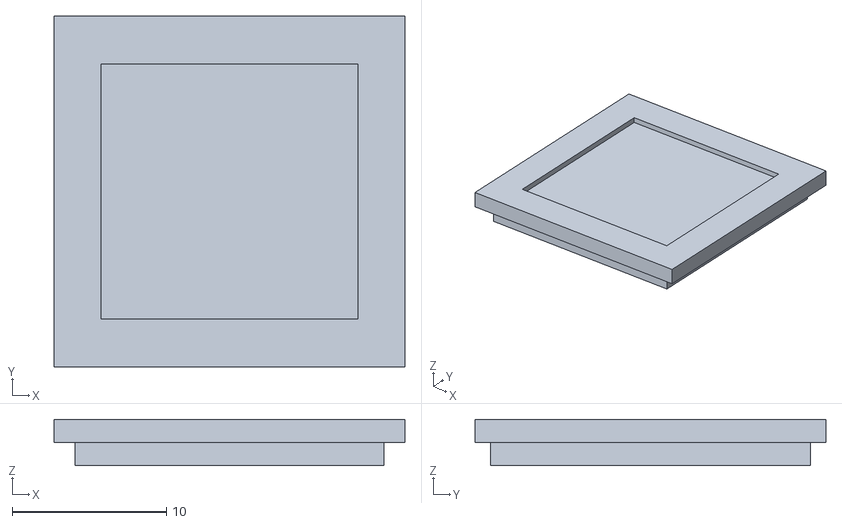
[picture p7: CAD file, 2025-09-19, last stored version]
Encapsulado/Box/files/Supply_Drop_Lid_Fixed.stl
22.8 x 22.8 x 3.00

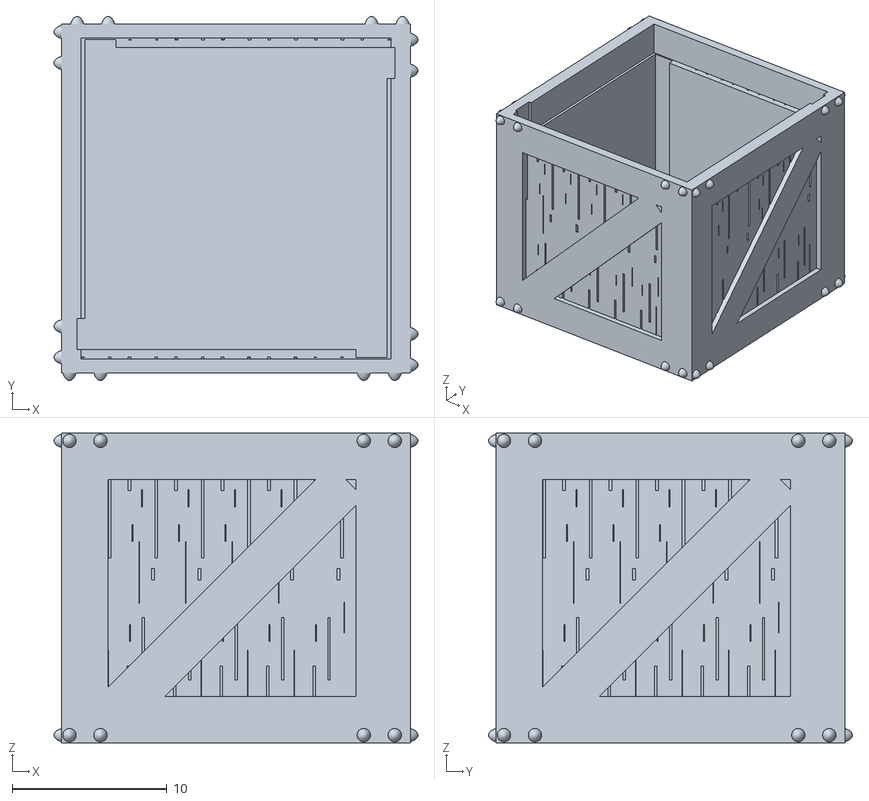
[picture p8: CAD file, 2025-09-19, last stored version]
Encapsulado/Box/files/Supply_Drop_Box_Fixed.stl
23.5 x 23.5 x 20.0

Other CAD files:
Encapsulado/Box/files/Supply_Drop_Lid_Loose.stl

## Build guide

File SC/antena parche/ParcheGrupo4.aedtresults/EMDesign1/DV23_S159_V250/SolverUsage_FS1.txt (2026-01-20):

    VersionID HFSS2016
    Success 1
    SolverName IESolver
    IterativeSolver 0
    DistributedSolver 0
    Precision 2
    NumTasks 1
    NumUnknowns 310
    BasisOrder 0
    TREECOTREE 0
    MemoryMasterMB 161.339844
    MemoryTotalMB 161.339844

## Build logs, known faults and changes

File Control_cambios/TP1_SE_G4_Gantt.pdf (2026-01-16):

Taller de Proyectos 1 | 16 ene 2026
Grupo 4 | http://

Encargado del proyecto
Fechas de inicio y fin del proyecto | 16 sept 2025 - 6 feb 2026
Progreso | 100%
Tarea | 117
Recursos | 6

Nombre | Fecha de inicio | Fecha de fin
ENTREGAS | 19/9/25 | 5/2/26
Entrega 1 | 19/9/25 | 19/9/25
Entrega 2 | 26/9/25 | 26/9/25
Entrega 3 | 3/10/25 | 3/10/25
Entrega 4 | 10/10/25 | 10/10/25
Entrega 5 | 17/10/25 | 17/10/25
Entrega 6 | 24/10/25 | 24/10/25
Entrega 7 | 31/10/25 | 31/10/25
Entrega 8 | 7/11/25 | 7/11/25
Entrega 9 | 21/11/25 | 21/11/25
Entrega 10 | 28/11/25 | 28/11/25
Entrega 11 | 5/12/25 | 5/12/25
Entrega 12 | 12/12/25 | 12/12/25
Entrega 13 | 19/12/25 | 19/12/25
Entrega 14 | 16/1/26 | 16/1/26
Fecha Entrega Final | 6/2/26 | 6/2/26
Especificación del proyecto | 16/9/25 | 19/9/25
Definición de objetivos | 16/9/25 | 19/9/25
Estudio sistema y planificación | 16/9/25 | 19/9/25
PCB0: Diseño electrónico y captura esquemática | 22/9/25 | 13/10/25
Búsqueda de componentes | 22/9/25 | 22/9/25
Posicionado componentes | 23/9/25 | 29/9/25
Creación de nuevos componentes | 30/9/25 | 6/10/25
Taller de Proyectos 1 | 16 ene 2026
Tarea | 2

Nombre | Fecha de inicio | Fecha de fin
Documentación esquemático. Control de cambios | 7/10/25 | 9/10/25
Análisis consumo eléctrico | 7/10/25 | 13/10/25
Análisis disipación de potencia | 7/10/25 | 13/10/25
Rutado de conexiones | 7/10/25 | 13/10/25
Generación de listado de materiales (BOM) | 23/9/25 | 30/9/25
PCB1: Diseño electrónico y captura esquemática | 22/9/25 | 13/10/25
Búsqueda de componentes | 22/9/25 | 22/9/25
Posicionado componentes | 23/9/25 | 29/9/25
Creación de nuevos componentes | 30/9/25 | 6/10/25
Documentación esquemático. Control de cambios | 7/10/25 | 9/10/25
Análisis consumo eléctrico | 7/10/25 | 13/10/25
Análisis disipación de potencia | 7/10/25 | 13/10/25
Rutado de conexiones | 7/10/25 | 13/10/25
Generación de listado de materiales (BOM) | 23/9/25 | 30/9/25
PCB2: Diseño electrónico y captura esquemática | 22/9/25 | 13/10/25
Búsqueda de componentes | 22/9/25 | 22/9/25
Posicionado componentes | 23/9/25 | 29/9/25
Creación de nuevos componentes | 30/9/25 | 6/10/25
Documentación esquemático. Control de cambios | 7/10/25 | 9/10/25
Análisis consumo eléctrico | 7/10/25 | 13/10/25
Análisis disipación de potencia | 7/10/25 | 13/10/25
Rutado de conexiones | 7/10/25 | 13/10/25
Generación de listado de materiales (BOM) | 23/9/25 | 30/9/25
Tarea | 3

Nombre | Fecha de inicio | Fecha de fin
PCB3: Diseño electrónico y captura esquemática | 22/9/25 | 13/10/25
Búsqueda de componentes | 22/9/25 | 22/9/25
Posicionado componentes | 23/9/25 | 29/9/25
Creación de nuevos componentes | 30/9/25 | 6/10/25
Documentación esquemático. Control de cambios | 7/10/25 | 9/10/25
Análisis consumo eléctrico | 7/10/25 | 13/10/25
Análisis disipación de potencia | 7/10/25 | 13/10/25
Rutado de conexiones | 7/10/25 | 13/10/25
Generación de listado de materiales (BOM) | 23/9/25 | 30/9/25
PCB0: Diseño de la placa de circuito impreso | 16/10/25 | 28/10/25
Creación de huellas de nuevos componentes | 16/10/25 | 17/10/25
Posicionado de componentes | 16/10/25 | 16/10/25
Definición de borde y zonas de conectores | 16/10/25 | 16/10/25
Rutado de conexiones | 17/10/25 | 17/10/25
Planos de disipación térmica | 17/10/25 | 21/10/25
Planos de masa y otros | 21/10/25 | 21/10/25
Documentación: serigrafía. Control de cambios | 21/10/25 | 21/10/25
Documentación: acotaciones geométricas | 24/10/25 | 24/10/25
Generación de ficheros para el fabricante (gerber) | 24/10/25 | 28/10/25
PCB1: Diseño de la placa de circuito impreso | 16/10/25 | 28/10/25
Creación de huellas de nuevos componentes | 16/10/25 | 17/10/25
Posicionado de componentes | 16/10/25 | 16/10/25
Tarea | 4

Nombre | Fecha de inicio | Fecha de fin
Definición de borde y zonas de conectores | 16/10/25 | 16/10/25
Rutado de conexiones | 17/10/25 | 17/10/25
Planos de disipación térmica | 17/10/25 | 21/10/25
Planos de masa y otros | 21/10/25 | 21/10/25
Documentación: serigrafía. Control de cambios | 21/10/25 | 21/10/25
Documentación: acotaciones geométricas | 24/10/25 | 24/10/25
Generación de ficheros para el fabricante (gerber) | 24/10/25 | 28/10/25
PCB2: Diseño de la placa de circuito impreso | 16/10/25 | 28/10/25
Creación de huellas de nuevos componentes | 16/10/25 | 17/10/25
Posicionado de componentes | 16/10/25 | 16/10/25
Definición de borde y zonas de conectores | 16/10/25 | 16/10/25
Rutado de conexiones | 17/10/25 | 17/10/25
Planos de disipación térmica | 17/10/25 | 21/10/25
Planos de masa y otros | 21/10/25 | 21/10/25
Documentación: serigrafía. Control de cambios | 21/10/25 | 21/10/25
Documentación: acotaciones geométricas | 24/10/25 | 24/10/25
Generación de ficheros para el fabricante (gerber) | 24/10/25 | 28/10/25
PCB3: Diseño de la placa de circuito impreso | 16/10/25 | 28/10/25
Creación de huellas de nuevos componentes | 16/10/25 | 17/10/25
Posicionado de componentes | 16/10/25 | 16/10/25
Definición de borde y zonas de conectores | 16/10/25 | 16/10/25
Rutado de conexiones | 17/10/25 | 17/10/25
Planos de disipación térmica | 17/10/25 | 21/10/25
Tarea | 5

Nombre | Fecha de inicio | Fecha de fin
Planos de masa y otros | 21/10/25 | 21/10/25
Documentación: serigrafía. Control de cambios | 21/10/25 | 21/10/25
Documentación: acotaciones geométricas | 24/10/25 | 24/10/25
Generación de ficheros para el fabricante (gerber) | 24/10/25 | 28/10/25
Fabricación de la placa de circuito impreso | 18/11/25 | 8/12/25
Envío al fabricante | 18/11/25 | 22/11/25
Recepción y Revisión | 28/11/25 | 29/11/25
Montaje de componentes | 2/12/25 | 8/12/25
Realización Hardware FPGA. | 28/11/25 | 18/12/25
Core: LarVa | 28/11/25 | 14/12/25
Periféricos: UART0/1/2, SPI0/1, Temporizador, GPOut, GPIn | 16/12/25 | 18/12/25
Simulación | 2/12/25 | 18/12/25
Verificación hardware | 9/12/25 | 20/1/26
Verificación inicial | 9/12/25 | 9/12/25
Análisis de prestaciones | 16/12/25 | 18/12/25
Montaje final. Piezas mecánicas | 19/12/25 | 19/12/25
Verificación firmware | 13/1/26 | 15/1/26
Resolución de problemas | 16/1/26 | 18/1/26
Pruebas de Campo | 20/1/26 | 20/1/26
Realización Firmware. Simulación y depuración | 12/12/25 | 18/1/26
Control de elementos hardware: drivers | 12/12/25 | 28/12/25
Tarea | 6

Nombre | Fecha de inicio | Fecha de fin
Verificación | 8/1/26 | 10/1/26
Programa inicial. Especificaciones | 16/12/25 | 10/1/26
Documentación firmware. Control de cambios | 9/1/26 | 18/1/26
Documentación | 10/11/25 | 1/2/26
Realización informe | 10/11/25 | 1/2/26
Tarea | 7

Nombre | Función
Alonso | Indefinido
Andrés | Indefinido
Iván | Indefinido
Lucía | Indefinido
Víctor | Indefinido
Supervisor de proyecto | Indefinido

## Recursos

8

## Diagrama de Gantt

9

Nombre | Fecha de... | Fecha de fin
ENTREGAS | 19/9/25 | 5/2/26
Especificación del proyecto | 16/9/25 | 19/9/25
PCB0: Diseño electrónico y captura esquemática | 22/9/25 | 13/10/25
PCB1: Diseño electrónico y captura esquemática | 22/9/25 | 13/10/25
PCB2: Diseño electrónico y captura esquemática | 22/9/25 | 13/10/25
PCB3: Diseño electrónico y captura esquemática | 22/9/25 | 13/10/25
PCB0: Diseño de la placa de circuito impreso | 16/10/25 | 28/10/25
PCB1: Diseño de la placa de circuito impreso | 16/10/25 | 28/10/25
PCB2: Diseño de la placa de circuito impreso | 16/10/25 | 28/10/25
PCB3: Diseño de la placa de circuito impreso | 16/10/25 | 28/10/25
Fabricación de la placa de circuito impreso | 18/11/25 | 8/12/25
Realización Hardware FPGA. | 28/11/25 | 18/12/25
Verificación hardware | 9/12/25 | 20/1/26
Realización Firmware. Simulación y depuración | 12/12/25 | 18/1/26
Documentación | 10/11/25 | 1/2/26
2025 | | | | 2026
septiembre | octubre | noviembre | diciembre | enero | febrero | marzo
Entrega 1Entrega 2Entrega 3Entrega 4Entrega 5Entrega 6Entrega 7Entrega 8 | Entrega 9Entrega 10 Entrega 11 Entrega 12 Entrega 13 | Entrega 14 | Fecha Entrega Final

Diagrama de recursos | 10
septiembre | octubre | noviembre | diciembre | enero | febrero | marzo
Entrega 1Entrega 2Entrega 3Entrega 4Entrega 5Entrega 6Entrega 7Entrega 8 | Entrega 9Entrega 10 Entrega 11 Entrega 12 Entrega 13 | Entrega 14 | Fecha Entrega Final

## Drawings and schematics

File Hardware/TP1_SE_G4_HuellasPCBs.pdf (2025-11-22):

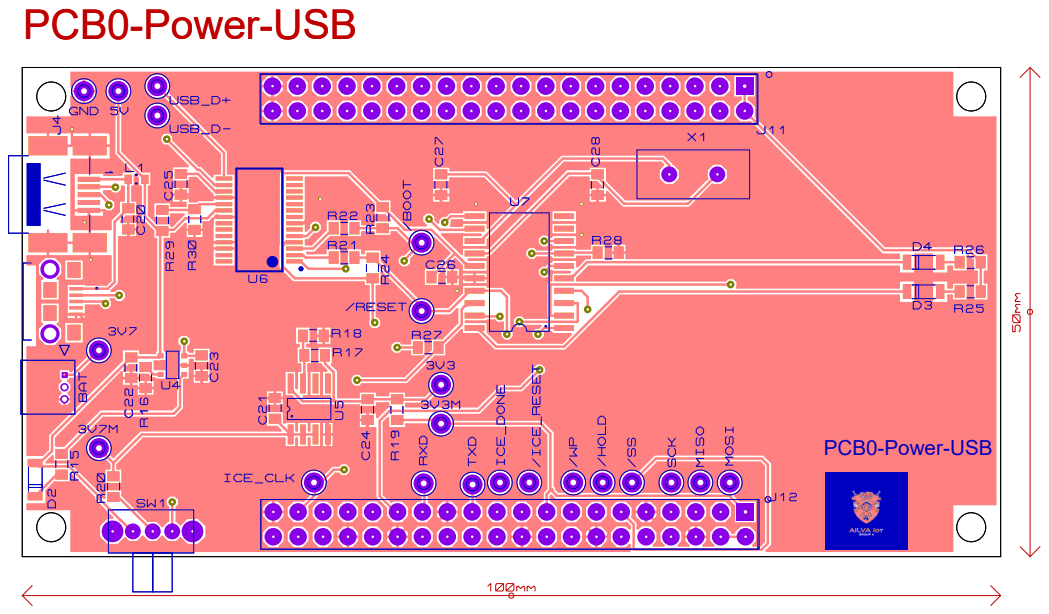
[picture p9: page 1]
PCB0-Power-USB

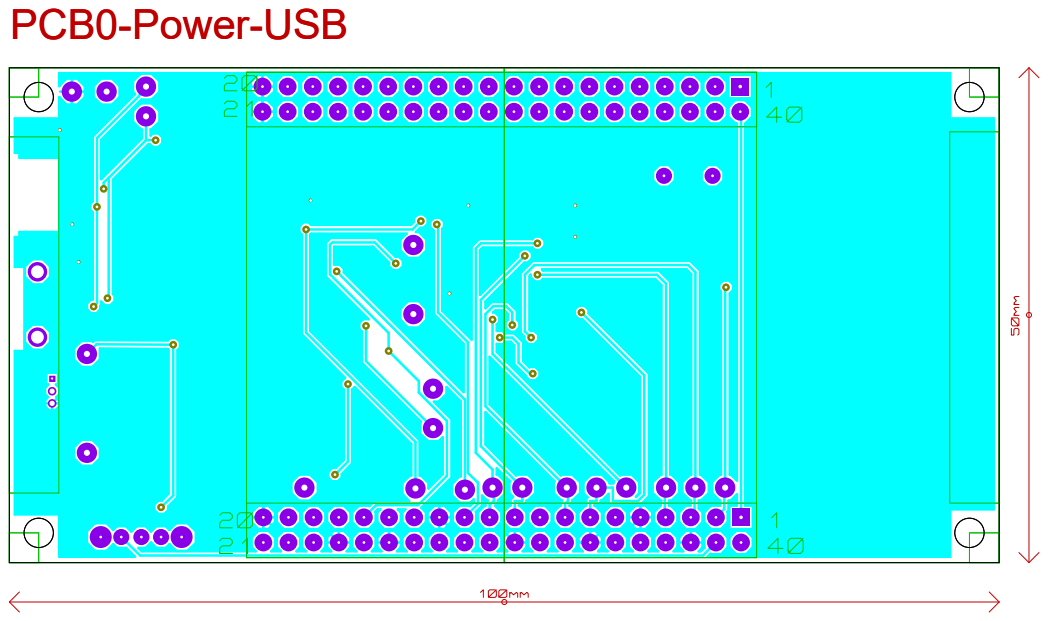
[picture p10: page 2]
PCB0-Power-USB

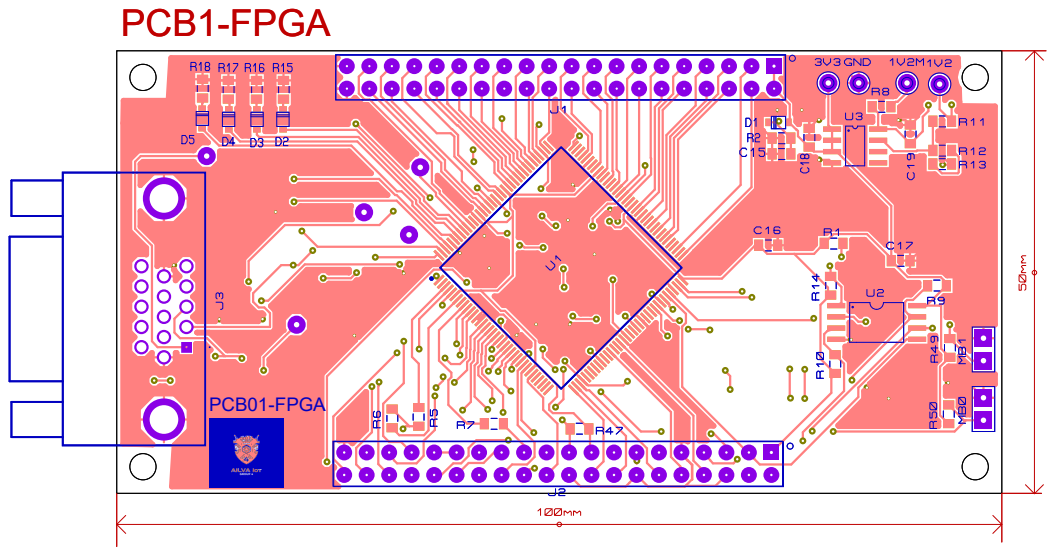
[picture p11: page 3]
PCB1-FPGA; PCB01-FPGA

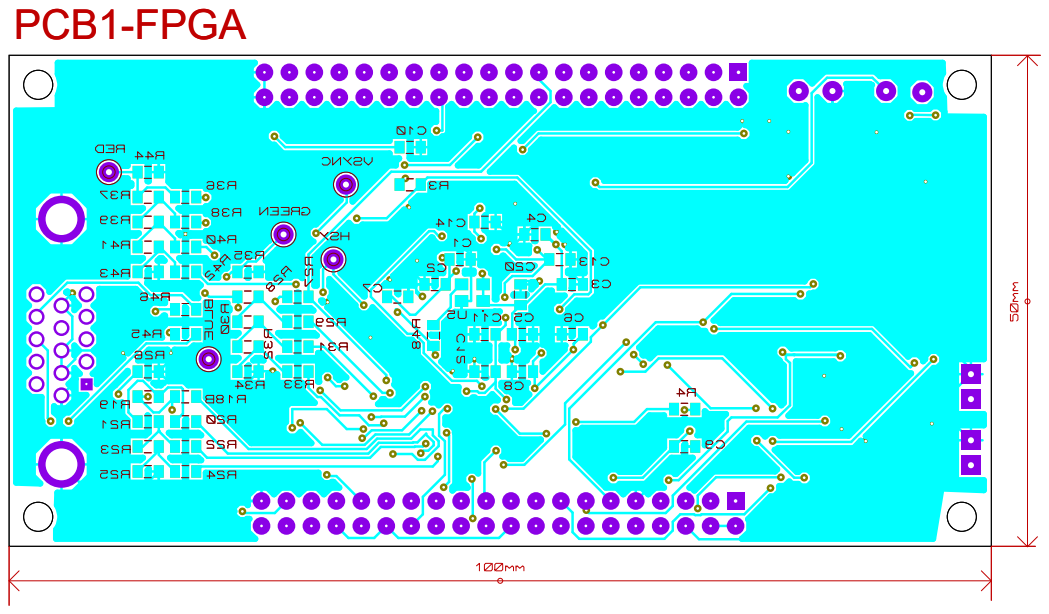
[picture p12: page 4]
PCB1-FPGA

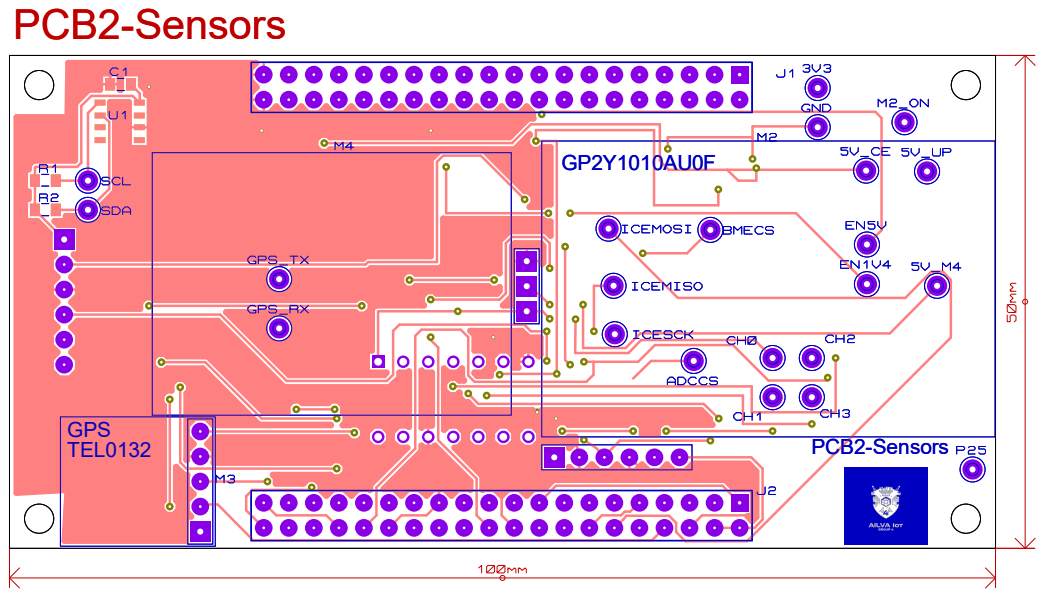
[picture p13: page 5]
PCB2-Sensors; TEL0132; GPS

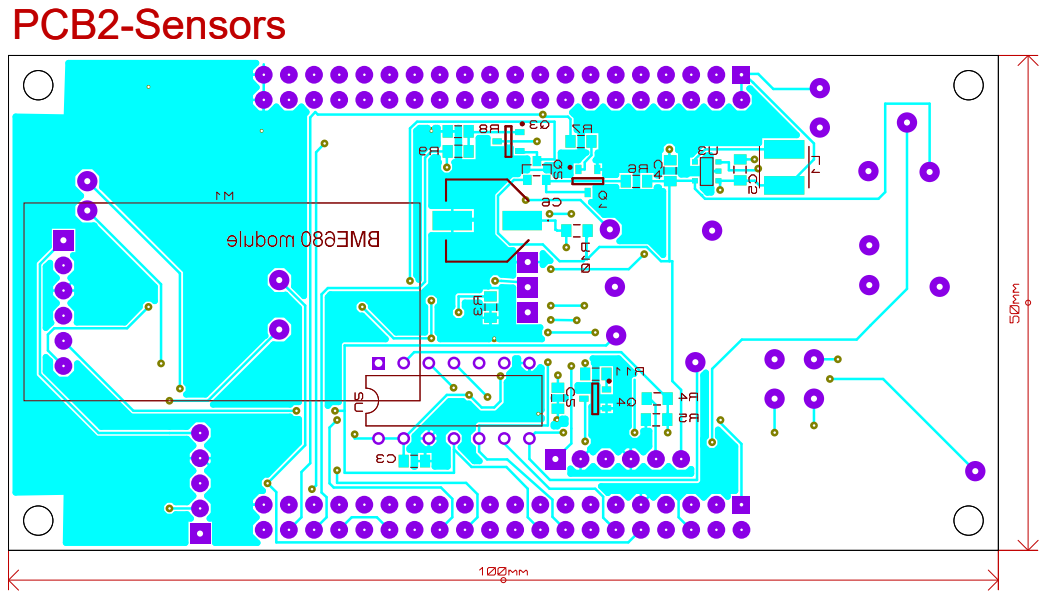
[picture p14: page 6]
PCB2-Sensors

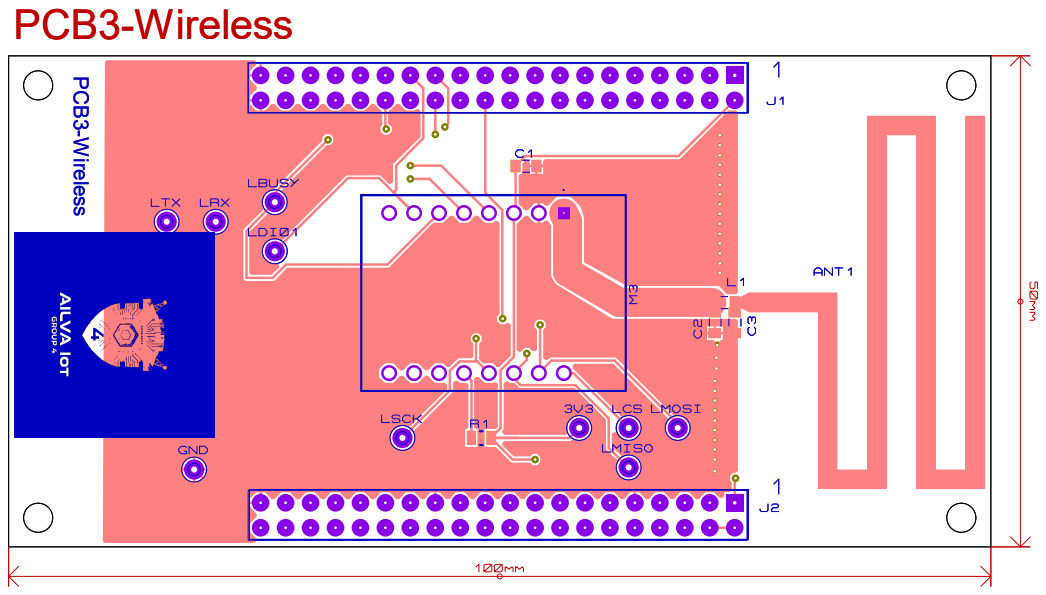
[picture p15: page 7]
PCB3-Wireless PCB3-Wireless

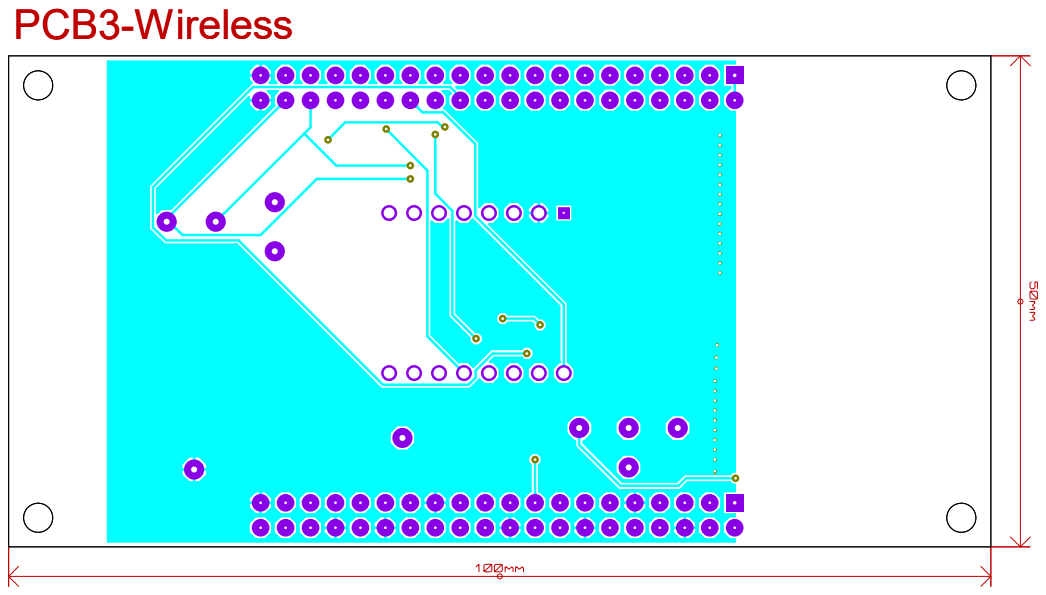
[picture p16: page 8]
PCB3-Wireless

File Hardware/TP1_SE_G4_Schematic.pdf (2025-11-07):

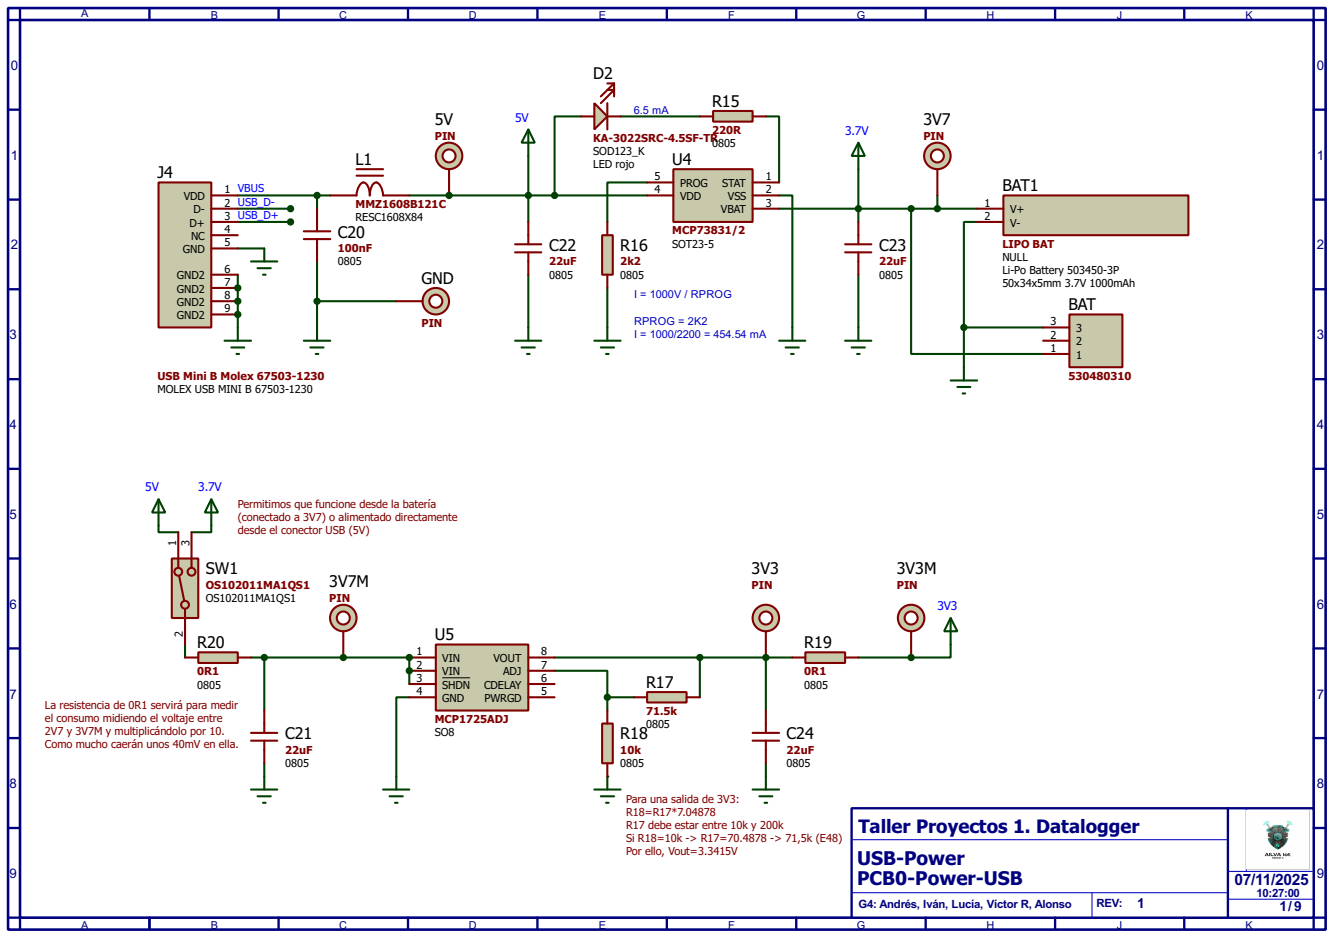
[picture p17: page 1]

USB Mini B Molex 67503-1230 MOLEX USB MINI B 67503-1230

Permitimos que funcione desde la batería
(conectado a 3V7) o alimentado directamente desde el conector USB (5V)

La resistencia de 0R1 servirá para medir el consumo midiendo el voltaje entre 2V7 y 3V7M y multiplicándolo por 10. Como mucho caerán unos 40mV en ella.

Para una salida de 3V3: R18=R17*7.04878 R17 debe estar entre 10k y 200k

Si R18=10k -> R17=70.4878 -> 71,5k (E48) Por ello, Vout=3.3415V

G4: Andrés, Iván, Lucía, Víctor R, Alonso

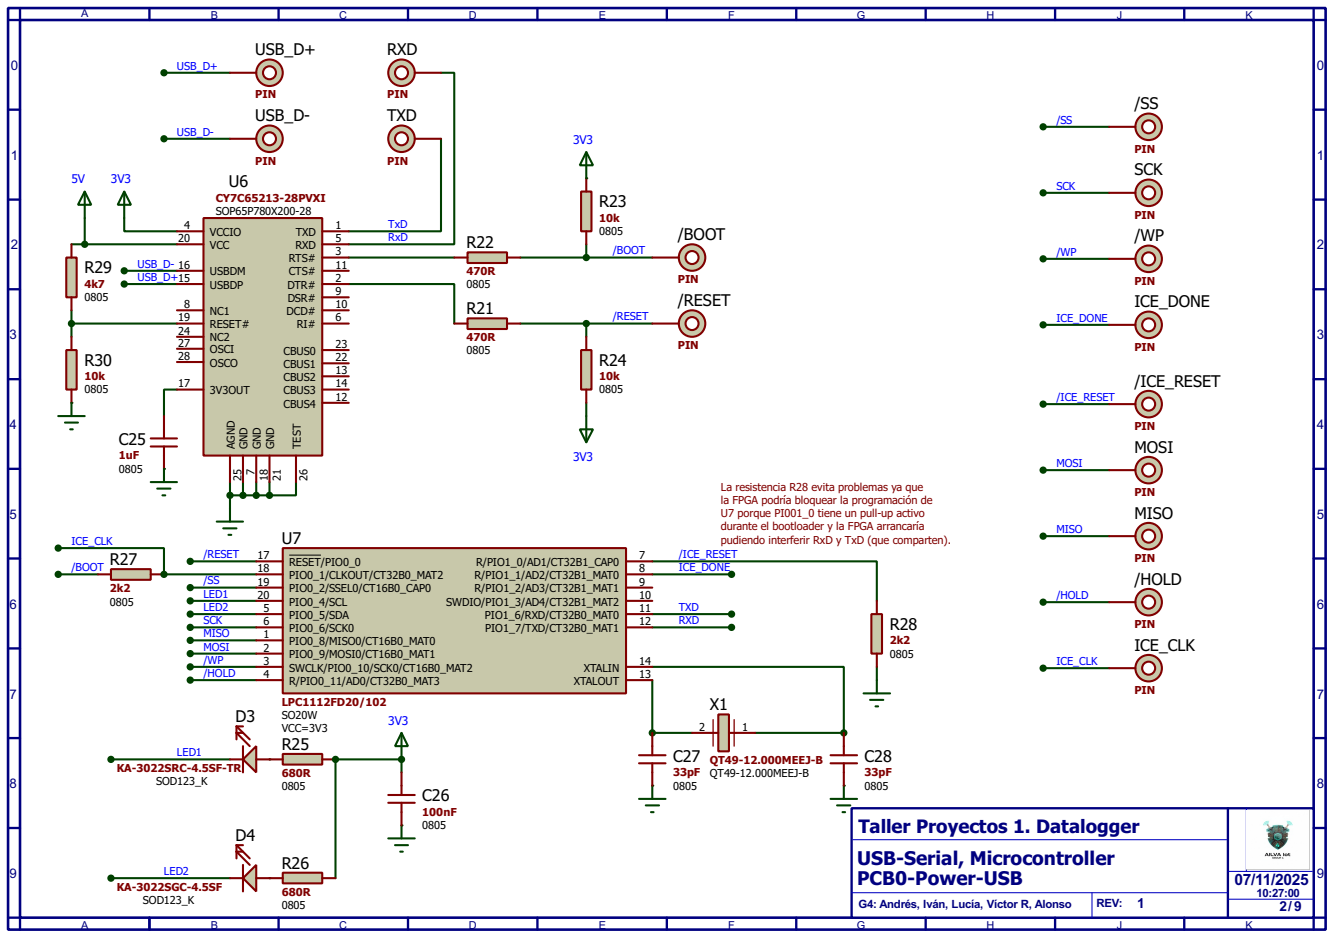
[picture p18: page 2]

La resistencia R28 evita problemas ya que
la FPGA podría bloquear la programación de U7 porque PI001_0 tiene un pull-up activo durante el bootloader y la FPGA arrancaría pudiendo interferir RxD y TxD (que comparten).

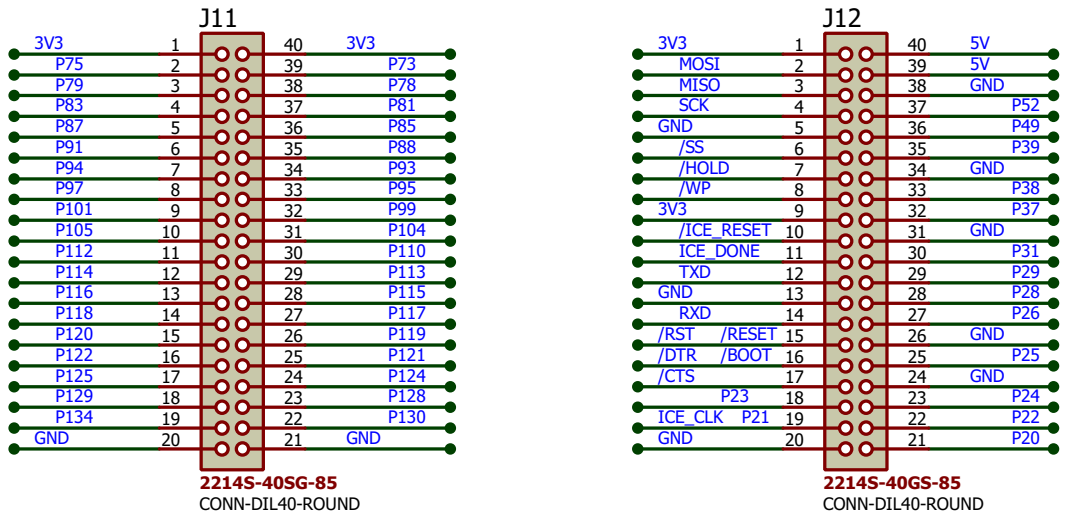
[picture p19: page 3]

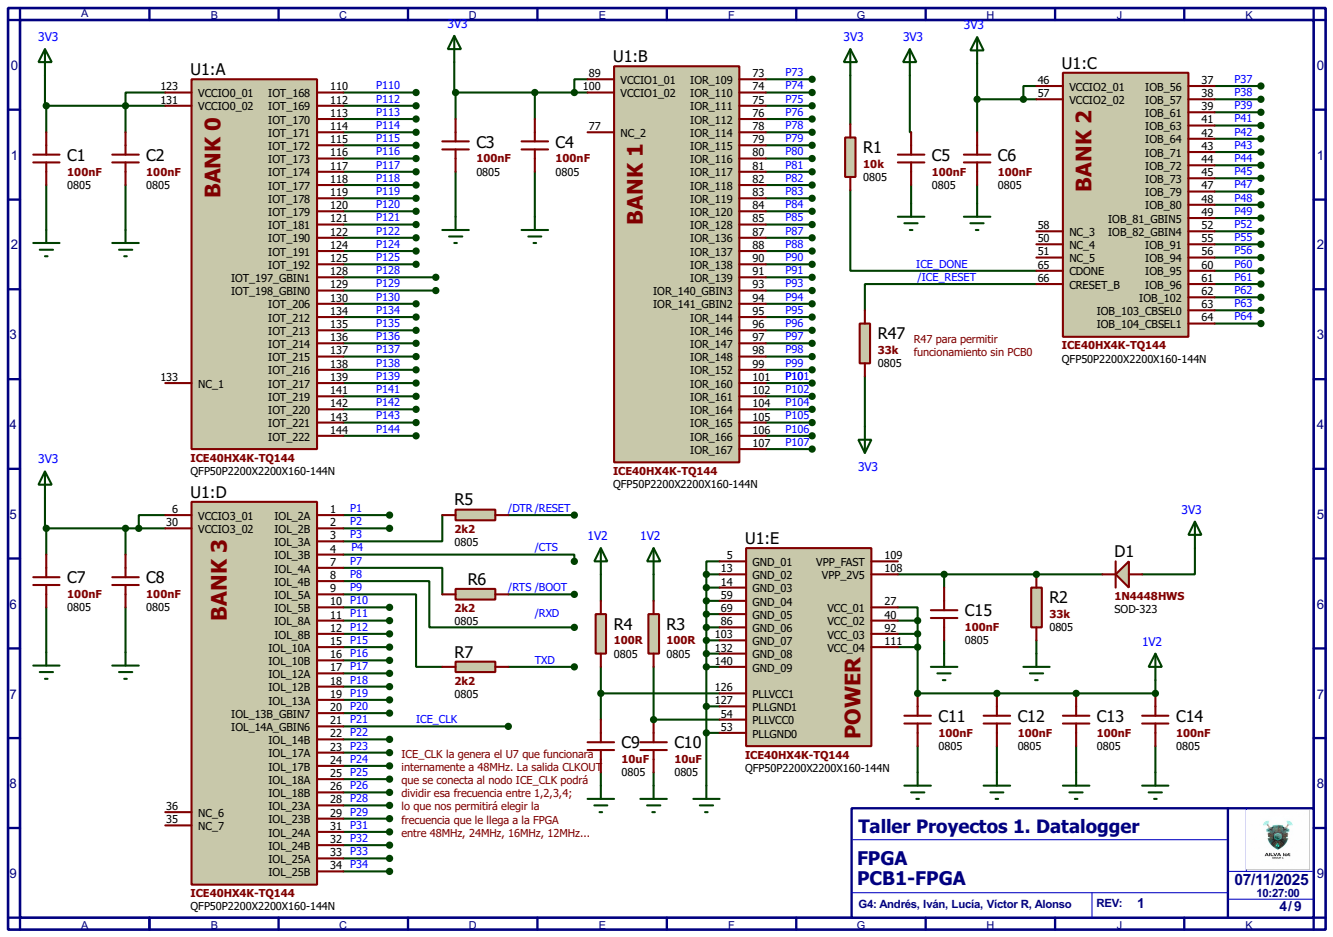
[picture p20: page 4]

8 | P8
P10 P11 P12 | /RXD

40 VCC_01

ICE_CLK la genera el U7 que funcionará
internamente a 48MHz. La salida CLKOUT
que se conecta al nodo ICE_CLK podrá
dividir esa frecuencia entre 1,2,3,4;
lo que nos permitirá elegir la
frecuencia que le llega a la FPGA
entre 48MHz, 24MHz, 16MHz, 12MHz...


Para una salida de 1V2: R11=Req*1.9286

J2 conector lado derecho. Montaje en lado bottom, footprint en top. Compatible R_pi 4

Si Req=4k7+1k5->R11=12k Por ello, Vout=1.2V

J1 conector lado izquierdo. Montake en el lado bottom, footprint en top.

____________________ NO NO Image 0 NO YES Image 1 YES NO Image 2 YES YES Image 3

Multiboot (jumpers)
Compilado con 'icemulti' Hasta 4 imágenes de config. de FPGA en Flash


VGA (Video Graphics Array) Analog output. Tres componentes de color analógica: RED, GREEN, BLUE; con 16 niveles cada uno. Usamos un convertidor DAC de tipo red R-2R. HSYNC sincronismo horizontal. VSYNC sincronismo vertical. Los niveles son de 0.7Vpp

7 | | 16 MH2
8 | | 17

La impedancia de la red de resistencias
se ha calculado para que sea de 75Oh. El acoplo de impedancias será correcto.


Dada la impedancia de la fuente de ADC_CH0 que es 10k||20k||6k8 = 3k3; la f máx del reloj SPI=1Mbps Dada la impedancia de la fuente de ADC_CH1 que es 1k2||10k = 1k; f máx.=1.1Mbps Usaremos 1Mbps para SCK del ADC.

Integrated pressure, humidity and temperature sensor

Para que la tensión máx. de salida de 3V7

Pulso 5.0V(60s) Pulso 1.4V(90s)
Salida para ADC. R sensor 2k-20k Divisor con R variable de 10k

Las señales de control son de 3V3 EN_5V_M4 EN_1V4_M4 5V_M4


Uso de pines de la FPGA: P28 5V_CE Enciende fuente 5v P22 EN_5V_M4 P24 EN_14V_M4 P25 Contgrola M2_ON_OFF P26 ADC_CS Activo en baja P28 SCL Tiene pull-up 10k P29 SDA Tiene pull-up 10k P31 0ME680_CS Activo en baja P37 ICE_SCK


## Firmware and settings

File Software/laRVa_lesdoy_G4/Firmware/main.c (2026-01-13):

#include <stdint.h>
#include <stdlib.h>


typedef unsigned char  u8;
typedef unsigned short u16;
typedef unsigned int   u32;

typedef signed char  s8;
typedef signed short s16;
typedef signed int   s32;

// Parámetros de calibración
uint32_t t_fine;
uint32_t temp_adc;
uint32_t temp_comp;
uint32_t temp_scaled;
uint32_t press_comp;
uint32_t press_adc;
uint32_t hum_adc;
uint32_t hum_comp;

uint32_t par_t1;
uint32_t par_t2;
uint32_t par_t3;

uint32_t par_p1;
uint32_t par_p2;
uint32_t par_p3;
uint32_t par_p4;
uint32_t par_p5;
uint32_t par_p6;
uint32_t par_p7;
uint32_t par_p8;
uint32_t par_p9;
uint32_t par_p10;

uint32_t par_h1;
uint32_t par_h2;
uint32_t par_h3;
uint32_t par_h4;
uint32_t par_h5;
uint32_t par_h6;
uint32_t par_h7;


//-- Registros mapeados
	//UART0
#define UARTDAT0  (*(volatile uint8_t*)0xE0000080)
#define UARTSTA0  (*(volatile uint32_t*)0xE0000084)
#define UARTBAUD0 (*(volatile uint32_t*)0xE0000084)
	//UART1
#define UARTDAT1  (*(volatile uint8_t*)0xE0000090)
#define UARTSTA1  (*(volatile uint32_t*)0xE0000094)
#define UARTBAUD1 (*(volatile uint32_t*)0xE0000094)
	//UART2
#define UARTDAT2  (*(volatile uint8_t*)0xE00000A0)
#define UARTSTA2  (*(volatile uint32_t*)0xE00000A4)
#define UARTBAUD2 (*(volatile uint32_t*)0xE00000A4)
	//SPI0
#define SPIDAT0	 (*(volatile uint32_t*)0xE0000070)
#define SPICTL0	 (*(volatile uint32_t*)0xE0000074)
#define SPISTA0	 (*(volatile uint32_t*)0xE0000074)
#define SPISS0	 (*(volatile uint32_t*)0xE0000078)
	//SPI1
#define SPIDAT1	 (*(volatile uint32_t*)0xE0000060)
#define SPICTL1	 (*(volatile uint32_t*)0xE0000064)
#define SPISTA1	 (*(volatile uint32_t*)0xE0000064)
#define SPISS1	 (*(volatile uint32_t*)0xE0000068)
	//TIMER
#define MAX_COUNT (*(volatile uint32_t*)0XE0000040)	
#define TIMER (*(volatile uint32_t*)0XE0000044)	
	//GPOUT/GPIN
#define GPOUT (*(volatile uint32_t*)0XE0000030)		
#define GPIN (*(volatile uint32_t*)0XE0000034)		
	//Interrupt enable
#define IRQEN	   		(*(volatile uint32_t*)0xE0000020)
	//Interrupt vectors
#define IRQVECT0   		(*(volatile uint32_t*)0xE0000000)
#define IRQVECT1   		(*(volatile uint32_t*)0xE0000004)
#define IRQVECT2   		(*(volatile uint32_t*)0xE0000008)
#define IRQVECT3   		(*(volatile uint32_t*)0xE000000C)
#define IRQVECT4   		(*(volatile uint32_t*)0xE0000010)
#define IRQVECT5  		(*(volatile uint32_t*)0xE0000014)
#define IRQVECT6   		(*(volatile uint32_t*)0xE0000018)
#define IRQVECT7   		(*(volatile uint32_t*)0xE000001C)
// Bits GPOUT/GPIN
	//GPOUT
#define LORA_RESET 	(1<<10)	
#define L_RX 		(1<<9)	
#define L_TX	 	(1<<8)	
#define EN_5V_UP 	(1<<7)	
#define EN_5V_M4 	(1<<6)
#define EN_1V4_M4 	(1<<5)	
#define M2_ON_OFF 	(1<<4)	
#define LED3 		(1<<3)	
#define LED2 		(1<<2)	
#define LED1 		(1<<1)	
#define LED0 		(1<<0)	
	//GPIN
#define LORA_DIO1 (1<<1)
#define LORA_BUSY (1<<0)		


// Registros sensor BME
#define RESET			0x60
#define CTRL_HUM   		0x72
#define BME_STATUS      0x73
#define CTRL_MEAS       0x74

// SPISS0 bits: [1] = BME680_CS, [0] = ADC_CS (activos bajos)
#define CS_NONE()      (SPISS0 = 0b11)  // Ninguno seleccionado
#define CS_BME_LOW()   (SPISS0 = 0b01)  // BME680 seleccionado
#define CS_ADC_LOW()   (SPISS0 = 0b10)  // ADC seleccionado



void delay_loop(uint32_t val);	// (3 + 3*val) cycles
#define CCLK (18000000)
#define _delay_us(n) delay_loop((n*(CCLK/1000)-3000)/3000)
#define _delay_ms(n) delay_loop((n*(CCLK/1000)-30)/3)


void _putch(int c)
{
	while((UARTSTA0&2)==0);
	//if (c == '\n') _putch('\r');
	UARTDAT0 = c;
}

void _puts(const char *p)
{
	while (*p)
		_putch(*(p++));
}

uint8_t _getch()
{
	while((UARTSTA0&1)==0);
	return UARTDAT0;
}

uint8_t haschar() {return UARTSTA0&1;}


#define putchar(d) _putch(d)
#include "printf.c"
#include "lora_sx1262.c"
//#include "BME_decoder.c"

const static char *menutxt="\n"
"    :::     ::::::::::: :::    :::     :::     :::          ::::::::::: :::::::: ::::::::::: \n"
"  :+: :+:       :+:     :+:    :+:     :+:   :+: :+:            :+:    :+:    :+:    :+:     \n"
" +:+   +:+      +:+     +:+    +:+     +:+  +:+   +:+           +:+    +:+    +:+    +:+     \n"
"+#++:++#++:     +#+     +#+    +#+     +:+ +#++:++#++:          +#+    +#+    +:+    +#+     \n"
"+#+     +#+     +#+     +#+     +#+   +#+  +#+     +#+          +#+    +#+    +#+    +#+     \n"
"#+#     #+#     #+#     #+#      #+#+#+#   #+#     #+#          #+#    #+#    #+#    #+#     \n"
"###     ### ########### ########## ###     ###     ###      ########### ########     ###     \n"
"------------------------------------------------\n"
"\n";             

uint8_t udat[32];
volatile uint8_t rdix,wrix;

/*uint8_t _getch()
{
	uint8_t d;
	while(rdix==wrix);
	d=udat[rdix++];
	rdix&=31;
	return d;
}
                     
uint8_t haschar() {return wrix-rdix;}*/

uint32_t __attribute__((naked)) getMEPC()
{
	asm volatile(
	"	.word	0x34101573 		\n"
	"	.word   0x34151073		\n"
	"	ret						\n"
	);
}

void __attribute__((interrupt ("machine"))) irq1_handler()
{
	_printf("\nTRAP at 0x%x\n",getMEPC());
}

void __attribute__((interrupt("machine"))) timer_handler(void)
{
    (void)TIMER;     // limpia flag de IRQ del timer
    static int toggle = 0;
    if (toggle) GPOUT |= LED0;
    else        GPOUT &= ~LED0;
    toggle = !toggle;
}

void __attribute__((interrupt ("machine"))) irq2_handler()
{
	udat[wrix++]=UARTDAT0;
	wrix&=31;
}

void  __attribute__((interrupt ("machine"))) irq3_handler(){
	static uint8_t a=32;
	UARTDAT0=a;
	if (++a>=128) a=32;
}

//GPS
char tramasGPS [200];
int j = 0;
int mensajeEmpezado = 0;
volatile int gps_msg_ready = 0;

void gpsDecoder(const char *nmeaSentence);
void miMemset(char *str, char value, int size);

void  __attribute__((interrupt ("machine"))) gpsSensor(){

	if(UARTDAT1 == '$'){
		j = 0;
		mensajeEmpezado = 1;
		tramasGPS[j] = UARTDAT1;
		//_printf("%c",tramasGPS[j]);
		j++;
		}
	else if(UARTDAT1 != '\n' && mensajeEmpezado == 1){
		tramasGPS[j] = UARTDAT1;
		//_printf("%c",tramasGPS[j]);
		j++;
	}
	else if(UARTDAT1 == '\n' && mensajeEmpezado == 1){
		tramasGPS[j]='\0';
		//_printf("%s\n", tramasGPS);
		gps_msg_ready = 1;
		mensajeEmpezado = 0;
	}
}

// --------------------------------------------------------

uint32_t spixfer0 (uint32_t d)
{
	SPIDAT0=d;
	while(SPISTA0&1);
	return SPIDAT0;
}

uint32_t spixfer1 (uint32_t d)
{
	SPIDAT1=d;
	while(SPISTA1&1);
	return SPIDAT1;
}

// --------------------------------------------------------
 

#define BAUD 115200
#define NULL ((void *)0)

uint32_t getw()
{
	uint32_t i;
	i=_getch();
	i|=_getch()<<8;
	i|=_getch()<<16;
	i|=_getch()<<24;
	return i;
}

uint8_t *_memcpy(uint8_t *pdst, uint8_t *psrc, uint32_t nb)
{
	if (nb) do {*pdst++=*psrc++; } while (--nb);
	return pdst;
}

//---------------------SENSOR GPS--------------------------//

void miMemset(char *str, char value, int size){
	for(int i=0; i<size; i++){
		str[i]=value;
	}
}

char *mistrtok(char *str, const char delimiter) {
    static char *input = NULL; // Cadena estática para mantener el estado entre llamadas
    if (str != NULL) {
        input = str; // Asignar la nueva cadena
    }
    if (input == NULL) {
        return NULL; // No hay más tokens
    }

    // Encontrar el inicio del próximo token
    char *start = input;
    while (*input != '\0' && *input != delimiter) {
        input++;
    }

    // Si encontramos un delimitador, reemplazarlo por '\0'
    if (*input == delimiter) {
        *input = '\0';
        input++; // Mover el puntero al siguiente carácter
    } else {
        input = NULL; // No hay más tokens
    }

    return start;
}

int miatoi(const char *str) {
    int result = 0;
    int isNegative = 0;

    // Manejar números negativos
    if (*str == '-') {
        isNegative = 1;
        str++;
    }

    // Convertir dígitos
    while (*str >= '0' && *str <= '9') {
        result = result * 10 + (*str - '0');
        str++;
    }

    // Aplicar signo si es necesario
    if (isNegative) {
        result *= -1;
    }

    return result;
}


double convertToDecimal(char *coord, char direction){
	int degrees = (direction == 'N' || direction == 'S') ? 2 : 3;
    char degreesStr[4] = {0}; // Para almacenar los grados
    for (int i = 0; i < degrees; i++) {
        degreesStr[i] = coord[i];
    }

    double minutes = miatoi(coord + degrees);
    double decimal = miatoi(degreesStr) + (minutes / 60.0);

    if (direction == 'S' || direction == 'W') {
        decimal *= -1;
    }

    return decimal;
}

double latDecimal;
double lonDecimal;

void gpsDecoder(const char *nmeaSentence) {
    // Verificar si la sentencia es GNGLL
    if (nmeaSentence[0] != '$' || nmeaSentence[1] != 'G' || nmeaSentence[2] != 'N' || 
        nmeaSentence[3] != 'G' || nmeaSentence[4] != 'L' || nmeaSentence[5] != 'L') {
		//_printf("%s\n", nmeaSentence);
        return;
    }

    // Variables para almacenar datos extraídos
    char latitude[20] = {0}, longitude[20] = {0};
    char latDirection = 0, lonDirection = 0, status = 0, posMode = 0;
    char utcTime[10] = {0};
	
    // Copiar la sentencia para manipularla
    char sentenceCopy[100];
    for (int i = 0; nmeaSentence[i] != '\0'; i++) {
        sentenceCopy[i] = nmeaSentence[i];
    }
	
    // Usar mistrtok para dividir la cadena
    char *token = mistrtok(sentenceCopy, ',');
    int fieldIndex = 0;

    while (token != NULL) {
        fieldIndex++;
        switch (fieldIndex) {
            case 2: // Latitud
                for (int i = 0; token[i] != '\0'; i++) {
                    latitude[i] = token[i];
                }
                break;
            case 3: // Dirección de latitud
                latDirection = token[0];
                break;
            case 4: // Longitud
                for (int i = 0; token[i] != '\0'; i++) {
                    longitude[i] = token[i];
                }
                break;
            case 5: // Dirección de longitud
                lonDirection = token[0];
                break;
            case 6: // Hora UTC
                for (int i = 0; token[i] != '\0'; i++) {
                    utcTime[i] = token[i];
                }
                break;
            case 7: // Estado
                status = token[0];
                break;
            case 8: // Indicador del modo de posición
                posMode = token[0];
                break;
        }
		
        token = mistrtok(NULL, ',');
    }

    // Convertir latitud y longitud a formato decimal
    latDecimal = convertToDecimal(latitude, latDirection);
    lonDecimal = convertToDecimal(longitude, lonDirection);

    // Mostrar los resultados
	_printf("%s\n", nmeaSentence);
    _printf("Latitud: %d\n", latDecimal);
    _printf("Longitud: %d\n", lonDecimal);
    _printf("Hora UTC: %s\n", utcTime);
    _printf("Modo de posicion: %c\n\n", posMode);
}

// -------------------- SENSOR BME680 ---------------------
//BME_quick_start();
// Escribir en un registro en el BME680
void BME680_WriteRegister(uint8_t addr, uint8_t dato){

	CS_BME_LOW(); // Selección de dispositivo (Chip Select, CS = 0) BME_ADC = 0
	SPIDAT0 = addr & 0x7F; // WR (bit 7) = 0 y dirección (bits 6..0). Cuando se escribe MSB = 1
	while(SPISTA0 & 1); // Esperamos a que se complete la transferencia
	SPIDAT0 = dato; // Ponemos el dato
	while(SPISTA0 & 1); // Esperamos a que se complete la transferencia;
	CS_NONE(); // Deselección de dispositivo (Chip Select, CS = 1) BME_ADC = 1

}

// Leer un registro del BME860
uint8_t BME680_ReadRegister(uint8_t addr){

	uint8_t d;

	if(addr & 0x80) BME680_WriteRegister(0x73, 0x00); // Página 0, 0x80..0xFF

	CS_BME_LOW();
	SPIDAT0 = (1<<7) | addr; // WR (bit 7) = 0 y dirección (bits 6..0). Cuando se lee, MSB = 0
	while(SPISTA0 & 1); // Esperamos a que se complete la transferencia
	SPIDAT0 = 0; // Byte dummy, para recoger lectura
	while(SPISTA0 & 1); // Esperamos a que se complete la transferencia
	d = SPIDAT0;
	CS_NONE(); // BME_ADC = 1

	BME680_WriteRegister(BME_STATUS,(1<<4)); // Página 1, 0x00..0x7F
	
	return d;
}

// Inicialización básica del BME680
void BME680_Init(){
	
	// Configurar oversampling y modo
	BME680_WriteRegister(CTRL_HUM, 0b00000001); // Configurar oversampling de humedad
	BME680_WriteRegister(CTRL_MEAS, 0b01010100); // Temp 2x, Presión 16x, modo sleep

    // Página 1 de los registros
    BME680_WriteRegister(BME_STATUS,(0<<4));
	
    // Lectura del parámetro de calibración
	
    //temp_adc = (BME680_ReadRegister(0x24)>>4) | (BME680_ReadRegister(0x23)<<12) | (BME680_ReadRegister(0x22)<<4);
	//_printf("%d",temp_adc);

    // Página 0 de los registros 
    BME680_WriteRegister(BME_STATUS, (1<<4));

    // Lectura de los parámetros de calibración
    // --- Temperatura ---
	par_t1 =  (uint16_t)BME680_ReadRegister(0xEA) << 8;
	par_t1 += (uint16_t)BME680_ReadRegister(0xE9);

	par_t2 =  (uint16_t)BME680_ReadRegister(0x8B) << 8;
	par_t2 += (uint16_t)BME680_ReadRegister(0x8A);

	par_t3 = BME680_ReadRegister(0x8C);

	temp_adc  = (uint32_t)BME680_ReadRegister(0x22) << 12;
	temp_adc += (uint32_t)BME680_ReadRegister(0x23) << 4;
	temp_adc += (uint32_t)BME680_ReadRegister(0x24) >> 4;

	// --- Presión ---
	par_p1  = (uint16_t)BME680_ReadRegister(0x8F) << 8;
	par_p1 += (uint16_t)BME680_ReadRegister(0x8E);

	par_p2  = (uint16_t)BME680_ReadRegister(0x91) << 8;
	par_p2 += (uint16_t)BME680_ReadRegister(0x90);

	par_p3 = BME680_ReadRegister(0x92);

	par_p4  = (uint16_t)BME680_ReadRegister(0x95) << 8;
	par_p4 += (uint16_t)BME680_ReadRegister(0x94);

	par_p5  = (uint16_t)BME680_ReadRegister(0x97) << 8;
	par_p5 += (uint16_t)BME680_ReadRegister(0x96);

	par_p6 = BME680_ReadRegister(0x99);
	par_p7 = BME680_ReadRegister(0x98);

	par_p8  = (uint16_t)BME680_ReadRegister(0x9D) << 8;
	par_p8 += (uint16_t)BME680_ReadRegister(0x9C);

	par_p9  = (uint16_t)BME680_ReadRegister(0x9F) << 8;
	par_p9 += (uint16_t)BME680_ReadRegister(0x9E);

	par_p10 = BME680_ReadRegister(0xA0);

	press_adc  = (uint32_t)BME680_ReadRegister(0x1F) << 12;
	press_adc += (uint32_t)BME680_ReadRegister(0x20) << 4;
	press_adc += (uint32_t)BME680_ReadRegister(0x21) >> 4;

	// --- Humedad ---
	par_h1  = (uint16_t)(BME680_ReadRegister(0xE3) << 4);
	par_h1 += (uint16_t)(BME680_ReadRegister(0xE2) & 0x0F);

	par_h2  = (uint16_t)(BME680_ReadRegister(0xE1) << 4);
	par_h2 += (uint16_t)(BME680_ReadRegister(0xE2) & 0x0F);

	par_h3 = BME680_ReadRegister(0xE4);
	par_h4 = BME680_ReadRegister(0xE5);
	par_h5 = BME680_ReadRegister(0xE6);
	par_h6 = BME680_ReadRegister(0xE7);
	par_h7 = BME680_ReadRegister(0xE8);

	hum_adc  = (uint16_t)BME680_ReadRegister(0x25) << 8;
	hum_adc += (uint16_t)BME680_ReadRegister(0x26);

}
// Valor de temperatura recogido del sensor

uint32_t Temp_Value(){

    uint32_t var1, var2, var3;
	
	//temp_adc = (BME680_ReadRegister(0x24)>>4) | (BME680_ReadRegister(0x23)<<12) | (BME680_ReadRegister(0x22)<<4);
    var1 = ((int32_t)temp_adc >> 3) - ((int32_t)par_t1 << 1);  
    var2 = (var1 * (int32_t)par_t2) >> 11;  
    var3 = ((((var1 >> 1) * (var1 >> 1)) >> 12) * ((int32_t)par_t3 << 4)) >> 14;  
    t_fine = var2 + var3;  
    temp_comp = ((t_fine * 5) + 128) >> 8; 
		
    return temp_comp;
}

uint32_t Pressure_Value(){

    uint32_t var1, var2, var3;
	uint32_t press_raw = 1.4; // Pascales

    var1 = ((int32_t)t_fine >> 1) - 64000;  
    var2 = ((((var1 >> 2) * (var1 >> 2)) >> 11) * (int32_t)par_p6) >> 2;  
    var2 = var2 + ((var1 * (int32_t)par_p5) << 1);  
    var2 = (var2 >> 2) + ((int32_t)par_p4 << 16);  
    var1 = (((((var1 >> 2) * (var1 >> 2)) >> 13) * ((int32_t)par_p3 << 5)) >> 3) + (((int32_t)par_p2 * var1) >> 1);  
    var1 = var1 >> 18;  
    var1 = ((32768 + var1) * (int32_t)par_p1) >> 15;  

    press_comp = 1048576 - press_raw;  
    press_comp = (uint32_t)((press_comp - (var2 >> 12)) * ((uint32_t)3125));  

    if (press_comp >= (1 << 30)) press_comp = ((press_comp / (uint32_t)var1) << 1);  
    else press_comp = ((press_comp << 1) / (uint32_t)var1);  

    var1 = ((int32_t)par_p9 * (int32_t)(((press_comp >> 3) * (press_comp >> 3)) >> 13)) >> 12;  
    var2 = ((int32_t)(press_comp >> 2) * (int32_t)par_p8) >> 13;  
    var3 = ((int32_t)(press_comp >> 8) * (int32_t)(press_comp >> 8) * (int32_t)(press_comp >> 8) * (int32_t)par_p10) >> 17;  

    press_comp = (int32_t)(press_comp) + ((var1 + var2 + var3 + ((int32_t)par_p7 << 7)) >> 4); 

    return press_comp;
}

uint32_t Humidity_Value(uint32_t temp_comp){

    uint32_t var1, var2, var3, var4, var5, var6;

    temp_scaled = (int32_t)temp_comp;  

    var1 = (int32_t)hum_adc - (int32_t)((int32_t)par_h1 << 4) - (((temp_scaled * (int32_t)par_h3) / ((int32_t)100)) >> 1);  
    var2 = ((int32_t)par_h2 * (((temp_scaled * (int32_t)par_h4) / ((int32_t)100)) + (((temp_scaled * ((temp_scaled * (int32_t)par_h5) / ((int32_t)100))) >> 6) / ((int32_t)100)) + ((int32_t)(1 << 14)))) >> 10;  
    var3 = var1 * var2;  
    var4 = (((int32_t)par_h6 << 7) + ((temp_scaled * (int32_t)par_h7) / ((int32_t)100))) >> 4;  
    var5 = ((var3 >> 14) * (var3 >> 14)) >> 10;  
    var6 = (var4 * var5) >> 1;  

    hum_comp = (((var3 + var6) >> 10) * ((int32_t) 1000)) >> 12; 

    return hum_comp;
}


void main()
{
	char c,buf[17];
	uint8_t *p;
	unsigned int i,j;
	int n;
	void (*pcode)();
	uint32_t *pi;
	uint16_t *ps;
	uint32_t temp_comp, press_comp, hum_comp;


	UARTBAUD0=(CCLK+BAUD/2)/BAUD -1;		
	UARTBAUD1=(CCLK+9600/2)/9600 -1;	
	UARTBAUD2=(CCLK+BAUD/8)/BAUD -1;

	SPICTL0=0x0808;
	BME680_WriteRegister(CTRL_MEAS, 0x54); // Temp 2x, Presión 16x, modo sleep
	_printf("CTRL_MEAS=0x%02x\n", BME680_ReadRegister(CTRL_MEAS) );
	
	c = UARTDAT0;		// Clear RX garbage
	c = UARTDAT1;		// Clear RX garbage

	IRQVECT0=(uint32_t)irq1_handler;
	IRQVECT1=(uint32_t)timer_handler;
	IRQVECT2=(uint32_t)irq2_handler;
	IRQVECT3=(uint32_t)irq3_handler;
	IRQVECT4=(uint32_t)gpsSensor;

	IRQEN = 0;
	IRQEN |= (1<<1);        // bit 1: TIMER
	IRQEN |= (1<<2);        // bit 2: UART0 RX
	IRQEN |= (1<<4);  		// UART1 RX (GPS)

	MAX_COUNT = CCLK/1000 - 1;  // 1 ms a 18 MHz

	asm volatile ("ecall");
	asm volatile ("ebreak");

	_puts(menutxt);
	_puts("Hola mundo\n");
	
	while (1)
	{
			_puts("Command [123dxgtq]> ");
			char cmd = _getch();
			if (cmd > 32 && cmd < 127)
				_putch(cmd);
			_puts("\n");

			switch (cmd)
			{
			case '1':
			    _puts(menutxt);
				break;
			case '2':
				IRQEN^=2;	// Toggle IRQ enable for UART TX
				_delay_ms(100);
				break;
			case '3':
				_printf("--------------- DATOS GPS --------------\n");
					if (gps_msg_ready) {
						gps_msg_ready = 0;
						gpsDecoder(tramasGPS);   // parsea y hace printf aquí
					} else {
						_printf("No hay nueva trama GPS.\n");
					}
				_printf("--------------------------------------------------\n");    
				break;
			case 'x':
				_puts("Upload APP from serial port (<crtl>-F) and execute\n");
				if(getw()!=0x66567270) break;
				p=(uint8_t *)getw();
				n=getw();
				i=getw();
				if (n) {
					do { *p++=_getch(); } while(--n);
				}

				if (i>255) {
					pcode=(void (*)())i;
					pcode();
				} 
				break;
			case 'q':
				asm volatile ("jalr zero,zero");
				break;
			case 't': // Sensor temperatura, humedad y presión
				BME680_Init();
				temp_comp = Temp_Value(temp_adc);
				hum_comp = Humidity_Value(hum_adc);
				press_comp = Pressure_Value(press_adc);

				_printf("--------------- DATOS Temp/Hum/Pres --------------\n");
				_printf("\n Temperatura obtenida: ");
				_printf("%02d.%d%c", temp_comp/100, temp_comp%100, 167);
				//_printf(BME_gettemperature(0));
				_printf("\n Presion obtenida: ");
				_printf("%02d.%d%c",press_comp/100);
				//_printf(BME_getpressure());
				_printf("\n Humedad obtenida: ");
				_printf("%02d.%03d%c", hum_comp/1000, hum_comp%1000, 37);
				//_printf(BME_gethumidity());
				_printf("\n\n");
				_printf("--------------------------------------------------\n");    
				break;
			case 'g':
				if(IRQEN != 16){
					IRQEN = 16;
				}
				else{
					IRQEN = 1;
				}
				break;
			default:
				continue;
			}
	}
}

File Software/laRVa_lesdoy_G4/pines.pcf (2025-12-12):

# Uso de los pines de la FPGA (PCB1) 
#  del Taller de Proyectos 1 
# Máster en Telecomunicaciones 
# Universidad de Valladolid 
# Cursos 2022-2026 
#  Jesús M. Hernández & Jesús Arias 
 
# BANK 3 
 
set_io HSYNC      1 # HSYNC 
set_io P2         2  
set_io DTR        3 # /DTR /RESET 
set_io CTS        4 # /CTS 
       
set_io RTS        7 # /RTS /BOOT 
set_io TXD        8 #  
set_io RXD        9 #  
      
set_io GREEN3    10 # GREEN3 
set_io GREEN4    11 # GREEN2 
set_io GREEN1    12 # GREEN1 
set_io GREEN0    15 # GREEN0 
set_io BLUE3     16 # BLUE3 
set_io BLUE2     17 # BLUE2 
set_io BLUE1     18 # BLUE1 
set_io BLUE0     19 # BLUE0 
 
set_io EN_5V_UP  20 # HABILITA 5V_UP 
set_io CLKIN     21 # ICE_CLK 
set_io EN_5V_M4  22 # EN_5V 
set_io P23       23 
set_io EN_1V4_M4 24 # EN_1V4_M4 
set_io M2_ON_OFF 25 # M2_ON_OFF 
set_io ADC_CS    26 # ADC_CS 
       
set_io -pullup yes SDA       28 # SDA 
set_io -pullup yes SCL       29 # SCL 
 
set_io BME680_CS 31 # BME680_CS 
set_io P32       32   
set_io P33       33   
set_io P34       34   
 
# BANK 2 
 
set_io ICE_SCK   37 # ICE_SCK  
set_io ICE_MISO  38 # ICE_MISO 
set_io ICE_MOSI  39 # ICE_MOSI 
 
set_io P41       41   
set_io P42       42   
set_io P43       43   
set_io P44       44   
set_io P45       45   
     
set_io P47       47   
set_io P48       48   
set_io RXD1      49 # GPS_TX 

set_io TXD1      52 # GPS_RX 
set_io P55       55   
set_io P56       56 
        
set_io P60       60    
set_io P61       61    
set_io P62       62    
set_io MB1       63 # MB1   Jumpers multiboot 
set_io MB0       64 # MB0   Jumpers multiboot 
 
# SPI 
 
set_io MOSI      67 # MOSI 
set_io MISO      68 # MISO 
      
set_io SCK       70 # SCK 
set_io FSS       71 # /SS Flash 
 
# BANK 1 

set_io TCK       73 # * TCK, JTAG 
set_io P74       74  
set_io TMS       75 # * TMS, JTAG 
set_io P76       76  
          
set_io TDO       78 # * TDO, JTAG 
set_io TDI       79 # * TDI, JTAG 
set_io P80       80  
set_io P81       81 # * TRST, TAG 
 
set_io P82       82  
set_io P83       83 # * 
set_io P84       84  
set_io P85       85 # * 
          
set_io P87       87 # * 
set_io P88       88 # *  
 
set_io P90       90   
set_io P91       91 # *  
      
set_io P93       93 # * 
set_io P94       94 # * 
set_io P95       95 # *  
set_io P96       96   
set_io P97       97 # * 
set_io P98       98   
set_io P99       99 # * 
 
set_io P101     101 # *  
set_io P102     102  
     
set_io P104     104 # * 
set_io P105     105 # * 
set_io P106     106  
set_io P107     107  
 
# BANK 0 
 
set_io LORA_MOSI  110 # * LORA_MOSI 
         
set_io P112       112 # * 
set_io LORA_MISO  113 # * LORA_MISO 
set_io P114       114 # * 
set_io LORA_SCK   115 # * LORA_SCK 
set_io LORA_BUSY  116 # * LORA_BUSY 
set_io LORA_CS    117 # * LORA_CS  
set_io LORA_DIO1  118 # * DIO1 interrupt (LORA SX1262) 
set_io LORA_RESET 119 # * LORA_RESET 
     
set_io P120     120 # * 
set_io RXD2     121 # M1_TX ESP32-C3 
set_io P122     122 # * 
         
set_io TXD2     124 # M1_RX ESP32-C3 
set_io P125     125 # * 
 
set_io L_RX     128 # L_RX (LORA SX1262) 
set_io P129     129 # * 
         
set_io L_TX     130 # L_TX (LORA SX1262) 
set_io P134     134 # * 
set_io VSYNC    135 # VSYNC 
set_io ICE_LED1 136 # ICE_LED1 
set_io ICE_LED2 137 # ICE_LED2 
set_io ICE_LED3 138 # ICE_LED3 
set_io ICE_LED4 139 # ICE_LED4 
   
set_io RED3     141 # RED3 
set_io RED2     142 # RED2 
set_io RED1     143 # RED1 
set_io RED0     144 # RED0 

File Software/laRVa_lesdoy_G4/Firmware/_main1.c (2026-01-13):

#include <stdint.h>


#define putchar(d) _putch(d)
#include "printf.c"

typedef unsigned char  u8;
typedef unsigned short u16;
typedef unsigned int   u32;

typedef signed char  s8;
typedef signed short s16;
typedef signed int   s32;

//----------------------------------------
// Registros mapeados
//----------------------------------------

// UART0
#define UART0_DAT    (*(volatile uint8_t *) 0xE0000080)  // TX/RX data
#define UART0_BAUD   (*(volatile uint32_t*) 0xE0000084)  // Baud Divider (write)
#define UART0_FLAGS  (*(volatile uint32_t*) 0xE0000084)  // Flags (read)

// UART1
#define UART1_DAT    (*(volatile uint8_t *) 0xE0000090)
#define UART1_BAUD   (*(volatile uint32_t*) 0xE0000094)
#define UART1_FLAGS  (*(volatile uint32_t*) 0xE0000094)

// UART2
#define UART2_DAT    (*(volatile uint8_t *) 0xE00000A0)
#define UART2_BAUD   (*(volatile uint32_t*) 0xE00000A4)
#define UART2_FLAGS  (*(volatile uint32_t*) 0xE00000A4)

// SPI0
#define SPI0_DAT     (*(volatile uint32_t*) 0xE0000070)
#define SPI0_CTL     (*(volatile uint32_t*) 0xE0000074)
#define SPI0_SS      (*(volatile uint32_t*) 0xE0000078)

// SPI1
#define SPI1_DAT     (*(volatile uint32_t*) 0xE0000060)
#define SPI1_CTL     (*(volatile uint32_t*) 0xE0000064)
#define SPI1_SS      (*(volatile uint32_t*) 0xE0000068)

// TIMER
#define TIMER_MAXCNT (*(volatile uint32_t*) 0xE0000040)   // Write: MAX_COUNT
#define TIMER_CNT    (*(volatile uint32_t*) 0xE0000040)   // Read: TIMER

// GPOUT / GPIN
#define GPOUT_WRITE  (*(volatile uint32_t*) 0xE0000030)
#define GPOUT_READ   (*(volatile uint32_t*) 0xE0000030)
#define GPIN_READ    (*(volatile uint32_t*) 0xE0000034)

// IRQ
#define IRQ_ENABLE   (*(volatile uint32_t*) 0xE0000020)

#define IRQVECT0     (*(volatile uint32_t*) 0xE0000000)   // Trap
#define IRQVECT1     (*(volatile uint32_t*) 0xE0000004)   // Timer
#define IRQVECT2     (*(volatile uint32_t*) 0xE0000008)   // UART0 RX
#define IRQVECT3     (*(volatile uint32_t*) 0xE000000C)   // UART0 TX
#define IRQVECT4     (*(volatile uint32_t*) 0xE0000010)   // UART1 RX
#define IRQVECT5     (*(volatile uint32_t*) 0xE0000014)   // UART1 TX
#define IRQVECT6     (*(volatile uint32_t*) 0xE0000018)   // UART2 RX
#define IRQVECT7     (*(volatile uint32_t*) 0xE000001C)   // UART2 TX

//----------------------------------------
// Delays (idéntico al ejemplo)
//----------------------------------------
void delay_loop(uint32_t val);  // (3 + 3*val) cycles

#define CCLK (18000000)
#define _delay_us(n) delay_loop((n*(CCLK/1000000)-3)/3)
#define _delay_ms(n) delay_loop((n*(CCLK/1000)-3)/3)

//----------------------------------------
// UART helpers (sobre UART0 como consola)
//----------------------------------------
void _putch(int c)
{
    while ((UART0_FLAGS & 2) == 0);   // THRE en bit1
    UART0_DAT = (uint8_t)c;
}

void _puts(const char *p)
{
    while (*p) _putch(*(p++));
}

uint8_t udat[32];
volatile uint8_t rdix = 0, wrix = 0;

uint8_t _getch(void)
{
    uint8_t d;
    while (rdix == wrix);
    d = udat[rdix++];
    rdix &= 31;
    return d;
}

uint8_t haschar(void)
{
    return (uint8_t)(wrix - rdix);
}

//----------------------------------------
// RISC-V helpers
//----------------------------------------
uint32_t __attribute__((naked)) getMEPC(void)
{
    asm volatile(
        "   .word 0x34101573 \n"   // csrrw a0,mepc,zero
        "   .word 0x34151073 \n"   // csrrw zero,mepc,a0
        "   ret              \n"
    );
}

//----------------------------------------
// IRQ handlers
//----------------------------------------
void __attribute__((interrupt ("machine"))) irq_trap_handler(void)
{
    // aquí podrías imprimir usando _puts si tienes un printf mínimo
    _puts("\nTRAP at 0x");
    // impresión hexadecimal mínima de getMEPC()
    uint32_t x = getMEPC();
    for (int i = 0; i < 8; i++) {
        int nib = (x >> 28) & 0xF;
        _putch("0123456789ABCDEF"[nib]);
        x <<= 4;
    }
    _puts("\n");
}

void __attribute__((interrupt ("machine"))) irq_timer_handler(void)
{
    // leer TIMER para limpiar el flag de IRQ
    (void)TIMER_CNT;

    // ejemplo: parpadeo del LED0 en GPOUT (bit0)
    static uint32_t led = 0;
    led ^= 1;
    uint32_t v = GPOUT_READ;
    if (led) v |=  1u;
    else     v &= ~1u;
    GPOUT_WRITE = v;
}

void __attribute__((interrupt ("machine"))) irq0_rx_handler(void)
{
    udat[wrix++] = UART0_DAT;
    wrix &= 31;
}

void __attribute__((interrupt ("machine"))) irq0_tx_handler(void)
{
    static uint8_t a = 32;
    UART0_DAT = a;
    if (++a >= 128) a = 32;
}

void __attribute__((interrupt ("machine"))) irq1_rx_handler(void)
{
    udat[wrix++] = UART1_DAT;
    wrix &= 31;
}

void __attribute__((interrupt ("machine"))) irq1_tx_handler(void)
{
    static uint8_t a = 32;
    UART1_DAT = a;
    if (++a >= 128) a = 32;
}

void __attribute__((interrupt ("machine"))) irq2_rx_handler(void)
{
    udat[wrix++] = UART2_DAT;
    wrix &= 31;
}

void __attribute__((interrupt ("machine"))) irq2_tx_handler(void)
{
    static uint8_t a = 32;
    UART2_DAT = a;
    if (++a >= 128) a = 32;
}

// Si en algún momento quieres usar IRQs de UART1/2, añade aquí
// irq1_rx_handler, irq1_tx_handler, irq2_rx_handler, irq2_tx_handler
// y asigna sus direcciones a IRQVECT4..7.

//----------------------------------------
// SPI helper (SPI0 maestro sencillo)
//----------------------------------------
uint32_t spixfer(uint32_t d)
{
    SPI0_DAT = d;                 // escribir dato a enviar
    while (SPI0_CTL & 1);         // esperar mientras BUSY=1
    return SPI0_DAT;              // leer dato recibido
}

//----------------------------------------
// Serial helpers adicionales
//----------------------------------------
#define BAUD 115200
#define NULL ((void *)0)

uint32_t getw(void)
{
    uint32_t i;
    i  = (uint32_t)_getch();
    i |= (uint32_t)_getch() << 8;
    i |= (uint32_t)_getch() << 16;
    i |= (uint32_t)_getch() << 24;
    return i;
}

uint8_t *_memcpy(uint8_t *pdst, const uint8_t *psrc, uint32_t nb)
{
    if (nb) do { *pdst++ = *psrc++; } while (--nb);
    return pdst;
}
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

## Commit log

2025-09-26 Casi terminada PCB1
2025-09-26 CAMBIO EN PCB0
2025-09-26 PCB1 pag1 terminada
2025-09-26 PCB3 casi completa
2025-09-30 PCB1 terminada
2025-09-30 Agregada PCB0
2025-09-30 sensores 2
2025-10-03 Agregado Diagrama de GANTT + pdf
2025-10-03 fixed PCB0
2025-10-03 fixed PCB1
2025-10-03 PCB1 started
2025-10-03 PCBs Agregadas
2025-10-03 Delete ganttproject_plan.csv
    Eliminado GANTT previo
    [ganttproject_plan.csv]
2025-10-03 Delete datos.csv
    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
    [datos.csv]
2025-10-05 BOM con precios
    Faltan precios R, C, J, L
2025-10-10 Add files via upload
    BOM completa. Esquemático completo. Faltan testeos.
2025-10-10 Create Bill of Materials
2025-10-10 PCB1 bastante abvanzada 150 conexiones faltantes
2025-10-10 Agregado PCB0.pdf
2025-10-10 PCB0_diseñada
2025-10-10 sensores pcb
2025-10-10 PCB3 antena realizada
    Nota:
    Faltarían por situar los elementos de la cadena de adaptación de impedancias debido a que no se han calculado aun los valores de estos
2025-10-14 3 pcbs
2025-10-14 PCBs unidas
2025-10-14 Create bom folder
2025-10-15 TP1 corregido
    La antena estaría pendiente de terminarse al no poderse crear la huella
2025-10-16 PCB0 corregida y reloj creado
2025-10-17 Push pcbs
2025-10-17 fichero consumo empezado
    [Consumo_electrico.xlsx]
2025-10-17 pcb2 conexiones completo
2025-10-17 Esquemáticos y huellas
    Falta corregir huella PCB1
2025-10-24 Correcciones PCB, BOM y Schematics
2025-10-28 juntamos consumo en rama main
    [Consumo_electrico.xlsx]
2025-10-28 Ultima PCB actualizada
2025-10-28 PCB0 cambio
2025-10-28 Avances consumo
    [Consumo_electrico.xlsx]
2025-10-30 PDF PCBs
2025-10-30 Interconexion de tierras en PCB3
2025-11-07 Fin PCB
    [TP1_PCBs_Grupo4 - PCB0-Power-USB - CADCAM Bottom Copper.GBR, TP1_PCBs_Grupo4 - PCB0-Power-USB - CADCAM Bottom Solder Resist.GBR, TP1_PCBs_Grupo4 - PCB0-Power-U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]
2025-11-07 Entrega 8
    [TP1_PCBs_Grupo4 - PCB0-Power-USB - CADCAM Bottom Copper.GBR, TP1_PCBs_Grupo4 - PCB0-Power-USB - CADCAM Bottom Solder Resist.GBR, TP1_PCBs_Grupo4 - PCB0-Power-U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]
2025-11-21 consumo consumista comunista
    [Consumo_electrico.xlsx]
2025-11-22 GerberFiles added
    Gerber PCB3 sent
2026-01-16 Add new firmware files for gas sensor and LoRa communication
